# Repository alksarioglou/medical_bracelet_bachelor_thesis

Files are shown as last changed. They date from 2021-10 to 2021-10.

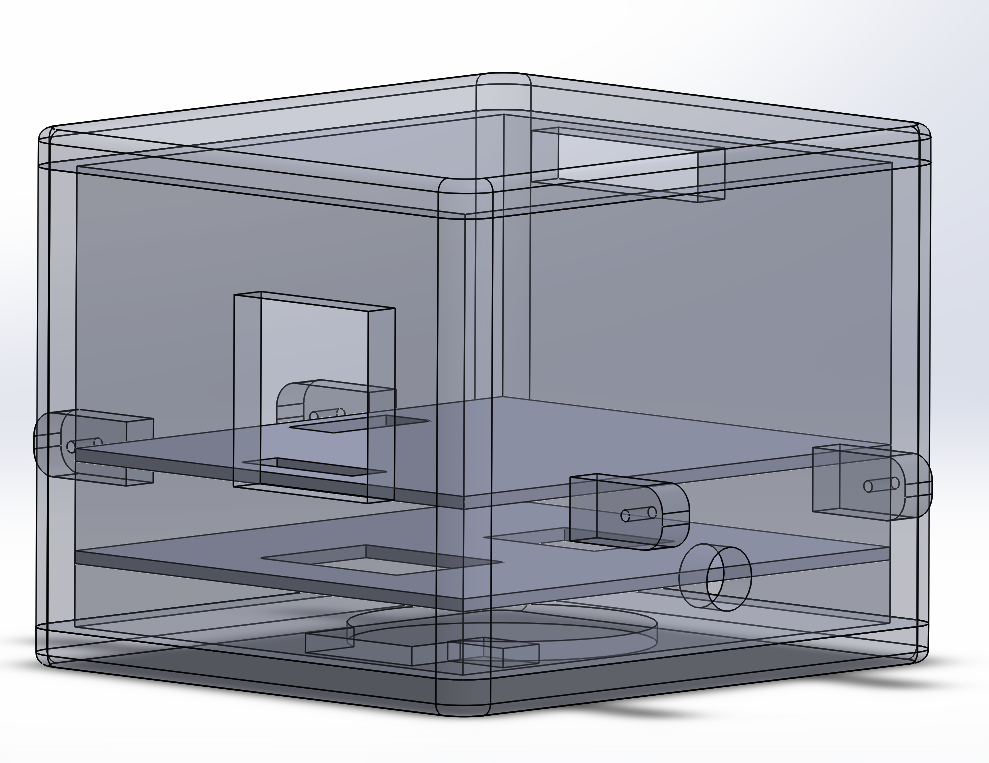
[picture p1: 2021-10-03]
CAD_Models/Non-transparent Intermediate Overview.png

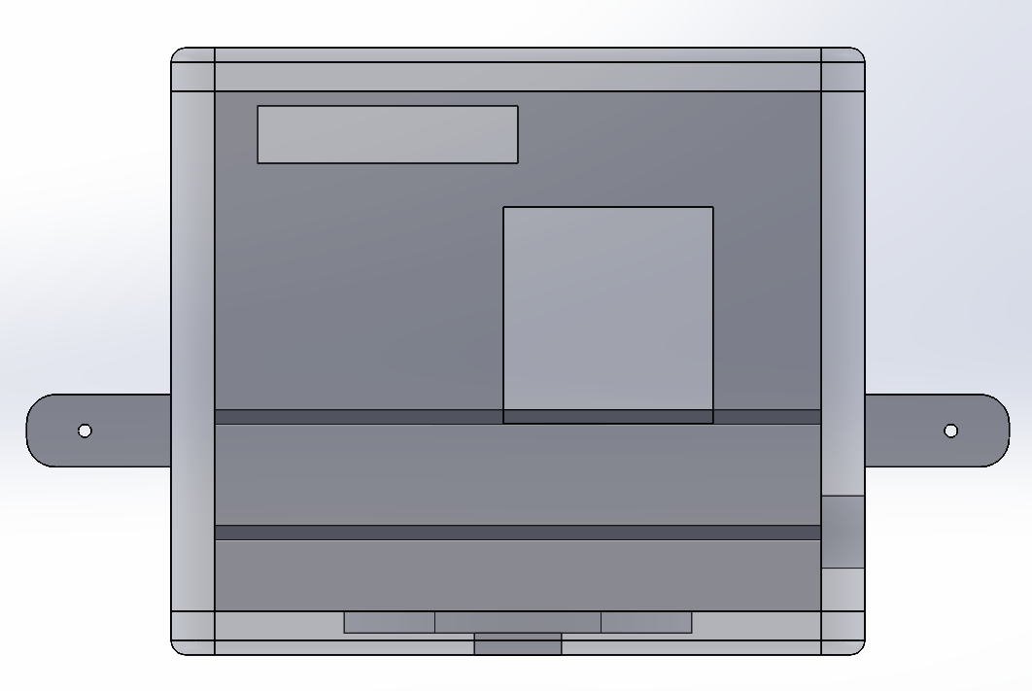
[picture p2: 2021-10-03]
CAD_Models/Non-transparent Intermediate Side View.png

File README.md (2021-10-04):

# Bachelor Thesis - Final Year Project - Medical Bracelet sends data (Heart-rate / ECG) to Webpage and Mobile App in real-time
- Development of a **portable medical bracelet** which combined both heart rate and electrocardiogram measurements transmitted wirelessly to a webpage and a mobile application in real-time 
- Achieved heart-rate measurements with **error of only 0.46% when compared to Apple Watch** 
- Sensor interface using **Arduino IDE**
- Webpage development using **Ubidots IoT Cloud Service**
- Mobile App development using **Blynk**
- Achieved **82% in the Bachelor Thesis (First-Class)**

## Organisation of Repository
- In `CAD_Models`, the 3D CAD designs of the bracelet are included which were implemented in **SolidWorks and 3D-printed**
- In `Component_Testing`, the source code used to test the heart-rate, ECG sensors and the Wi-Fi modules is presented (**Arduino and C++**)
- In `PCB`, the designs of the PCB integrating all components are found designed in **Altium PCB Designer**
- In `Reports`, all the **files that documented the progress of the project** throughout the year are presented

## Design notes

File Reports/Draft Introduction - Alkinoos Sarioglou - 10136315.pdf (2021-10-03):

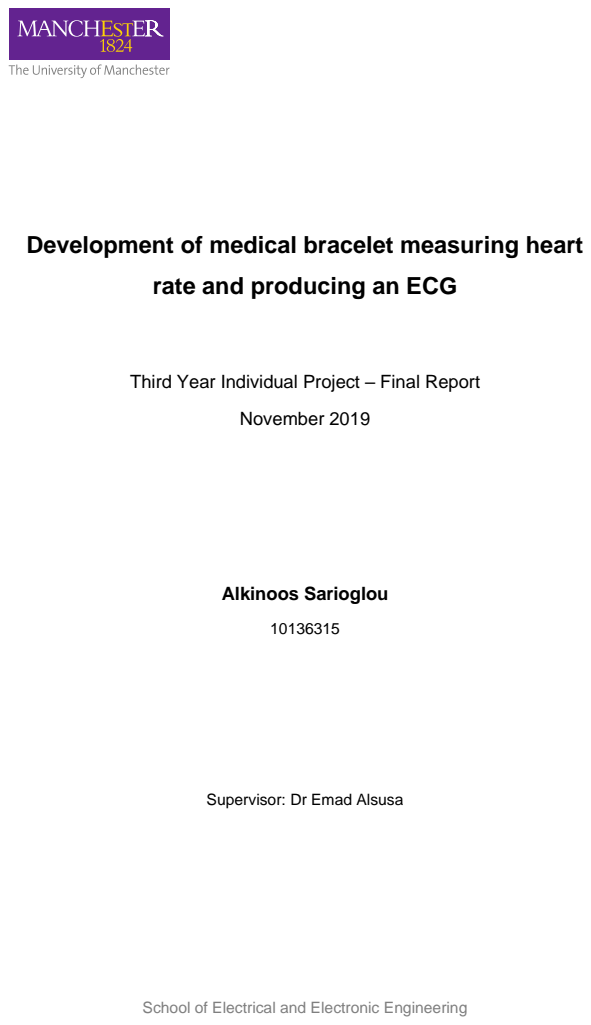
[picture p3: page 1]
November 2019; Alkinoos Sarioglou

Development of medical bracelet measuring heart

rate and producing an ECG

Third Year Individual Project – Final Report

Supervisor: Dr Emad Alsusa

School of Electrical and Electronic Engineering

School of Electrical and Electronic Engineering

Contents

School of Electrical and Electronic Engineering | Page 1

Introduction

Portable medical devices are becoming more popular these days due to the

revolutionization of this industry. Sensors that can measure the heart rate or produce

an electrocardiograph (ECG) have not only become more accurate but also smaller.

These are incorporated in wearable devices enabling people to track their own vital

measurements in real-time. As a result, regular meetings in the doctor are avoided

and heart abnormalities can be detected instantly leading to prompt treatment.

Undoubtedly, the advancement in medical devices should be accessible to all people

regardless of age, technological literacy or financial background. That is because the

data acquired by these devices are critical for everyone to stay healthy and diminish

the possibility of a fatal incident. However, the latest portable medical devices, in the

form of a bracelet mostly, discourage a wide range of people from using them due to

increased complexity and cost or due to limited functionality of communicating data

to a doctor in real time.

More specifically, some devices require connection to a nearby smart device, such

as a smartphone or a tablet. These gadgets are the only way to collect the recorded

data and display them for analysis and detection of potential flaws. This feature

already restricts many categories of people to have their vital data measured due to

limited abilities using technological equipment. There is a high possibility that the

ones affected the most are old people who most of the times do not possess one of

the smart devices. Ironically, they are the ones who need these devices the most, as

the measurements of heart rate and ECG need to be monitored constantly so that

dangerous situations can be dealt with immediately.

As it is understood taking real time and continuous measurements is the most

essential feature that these devices need to incorporate. Also, the communication of

these data to a specialist, such as a cardiologist, is critical so that the correct

interpretation of the results can be guaranteed and prevention of undesired incidents

is ensured. All of these characteristics are partially or not at all included in the

medical bracelets in the market, as they pose challenges in battery life and most of

all cost.

The increasing cost of development of such devices is reflected on the high selling

price. It is a fact that a lot of people are not able to afford prices that start from £80 and can reach the level of £500. Hence, it is understood that there are numerous

challenges to be overcome in the development of medical bracelets.

The aim of this project is to develop a low-cost medical bracelet which measures the

heart rate and the electrical activity of the heart continuously, in real time and can be

used without requiring a connected smart device. The communication of data will be

implemented through direct Wi-Fi to a cloud and the results will be displayed in a

webpage and an app. These two streams of displaying information will be used by

doctors to track the condition of their patients and detect abnormal activity. As a

result, they will be able to contact them directly and instruct them on which steps to

follow.

The main objectives of the project are directly related to the features that the medical

bracelet will incorporate. These include:

- Measurement of heart rate in BPM using a low-power heart rate sensor
- Measurement of the heart’s electrical activity using a low-power ECG sensor
- Communication of the above data to a cloud through direct Wi-Fi
- Display of the data on a webpage and an app in real time
- Development of app interface for doctors and patients

In order for the above to be achieved, a series of methods is followed. As a first step,

testing of different sensors for heart rate and ECG is performed in order to select the

ones which provide the best trade-off between cost, accuracy and size. Furthermore,

the available options in Wi-Fi modules are assessed in terms of cost, speed and

power consumption. A design of the overall circuit on a prototyping board follows

which integrates the mentioned components with the rest of the elements such as the

microcontroller and the battery. After that step is completed, the PCB is designed to

maximise the performance of the circuit and improve the communication of data

between the individual components.

The successful implementation of the PCB progresses the project to the software

development part. During this phase, the cloud is optimized to receive the data from

the Wi-Fi module. Following this, the webpage and the app are designed to collect

the information and display them in a user-friendly way. Finally, an early completion

of the above would allow for the 3D-printed design of the bracelet to be used with the system, otherwise an available one in the market will be used.

This report concludes the Final Year Project and summarizes the work undertaken

on planning, designing and implementing the low-cost medical bracelet. First, some

statistical figures related to fatal incidents from heart attacks or strokes prove the

need for this device. After that, the advantages and disadvantages of state-of-the-art

are thoroughly examined and the novel features of the proposed technology are

pointed out. Finally, the technical details of the project are presented and a

discussion of the results is included, assessing whether the project has been

successful in accomplishing the main aim.

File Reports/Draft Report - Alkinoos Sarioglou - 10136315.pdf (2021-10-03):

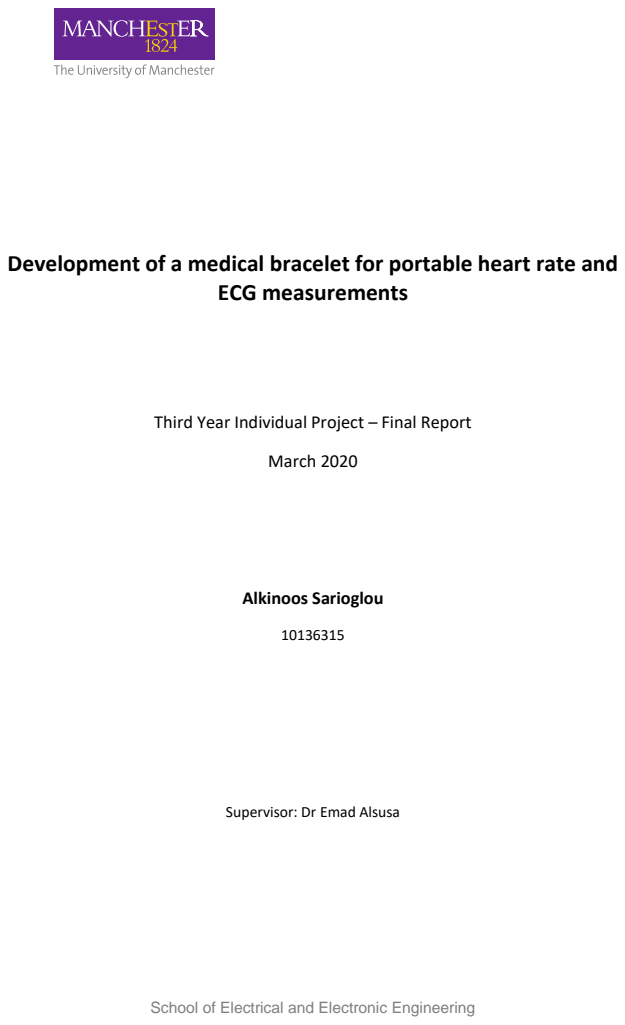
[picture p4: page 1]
ECG measurements; March 2020; Alkinoos Sarioglou

Development of a medical bracelet for portable heart rate and

Third Year Individual Project – Final Report

Supervisor: Dr Emad Alsusa

School of Electrical and Electronic Engineering

School of Electrical and Electronic Engineering

Contents

1.5.5. Recent research developments / Applications or implications of the research

13

School of Electrical and Electronic Engineering

School of Electrical and Electronic Engineering

2.8.3. Improving the Power Requirements and Cost | 58
2.8.4. Improving the Presentation of Results | 59
2.8.5. Improving the Security of Data | 59
Conclusions | 59
References | 60
Appendices | 64
Appendix 1 | 64
Appendix 2 | 67
Appendix 3 | 68
Appendix 4 | 72
Appendix 5 | 73
Presentation and Content (not included but marked) | 81
Formatting | 81
Spelling | 81
Grammar | 81
Figures | 81
Tables | 81
Diagrams | 81

Total word count: 17000

School of Electrical and Electronic Engineering | Page 1

Overview and Background

Abstract

It is a fact that heart attacks have always been responsible for a large number of deaths amongst

the population of the world. That is why since the beginning of medicine’s history, physicians have

been trying to find methods of identifying their symptoms in order to deal with them promptly

and save lives. One of the most efficient ways to detect these nowadays is heart monitoring. More

specifically, tracking of the electrical activity of the heart can demonstrate abnormalities of its

operation and immediate action can prevent fatal heart-related incidents. This would certainly

contribute to a patient’s longer lifetime.

There are two very important medical tools available today which enable doctors to check on the

vital information of their patients and acknowledge whether there are abnormalities or not. These

include the heart rate monitor and the electrocardiograph. The former one is using the technique

of photoplethysmography, in which an LED emits light on the skin and the amount of it reflected

to a photodiode is measured, demonstrating whether the change of blood’s volume is normal

during a heartbeat. The electrocardiograph is a device which uses electrodes attached to suitable

parts of the body in order to produce an electrocardiogram, a graph which monitors the electrical

activity of the heart by illustrating graphically whether its operation is regular. Therefore, it is

understood that these two tools should be easily accessible to all people in order to effectively

deal with heart-related accidents and as a result improve the life expectancy of the whole world

population.

In the last decade new technology has made these measurements available directly to the patients

with portable medical devices. Even though the existing state-of-the-art includes solutions which

extract vital information, the categories of people who can use them are limited due to the

following disadvantages:

- High cost
- Complex use of the technology
- Unable of communicating data to a doctor

The first problem constraints the use of these tools to people with limited financial background.

The second disadvantage does not allow older people with inadequate technological literacy to

have access to their medical information themselves. Finally, the feature of transmitting the live measurements to a doctor, in order for a meaningful analysis to be carried out, is missing from all

of the current state-of-the-art.

By considering these limitations, this project proposes the development of a low-cost medical

bracelet which can be easily worn by any patient on their wrist. The measurement of heart rate

and the electrocardiogram are produced in real time and are transmitted to a webpage or a

mobile application, where the doctors can view the information about their patients’ health and

take immediate action in case of an emergency.

In order for this to be achieved three components are necessary. First of all, a heart rate sensor is

required, which incorporates an LED and a photodiode, to extract the heart rate of the patient in

Beats Per Minute (BPM). Furthermore, an electrocardiograph sensor is used, which uses three

electrodes and measures the voltage difference between them, in order to produce the

electrocardiogram. In addition, a Wi-Fi module is added in order to communicate the data from

the sensors through an Internet-of-Things Cloud to a webpage and a mobile application. For all of

the above, different off-the-shelf components are tested and their accuracy is compared with the

Apple Watch Series 5 as a benchmark [1]. Then the most suitable ones are selected for the device

depending on the cost, size and accuracy. As a last step, a custom-made bracelet is designed, 3D-

printed and assembled with the circuit of the device to conclude the development of the proposed

solution.

The final part concerns a discussion which assesses whether the final product has accomplished its

aim in producing useful results for both patients and doctors. Also, the limitations of the

technology such as the accuracy of the sensors, the battery life and the charging time are analysed

and an evaluation on how they would restrict the device’s use by the customers is carried out.

Finally, the discussion investigates the further steps that would be followed should a marketing of

the product was decided, including Intellectual Property issues.

Future improvements: Reduce the parts about how I was planning to do it, e.g. too many details

about which components will be used and what the problems of the state-of-the-art is, put

more details on the results of the technical work after it is done, focus on the content of the

WHOLE report, put all additional background info in the Introduction. REDUCE SIZE

Introduction

Introduction of the project, get attention with the first sentence, give a hint of what you found out

through this project

Heart rate monitoring has been a priority of physicians and cardiologists since the beginning of the 20th century in the effort to deal with heart-related fatal incidents. The first big invention in this

field dates back to 1901, when Willem Einthoven created the first 3-lead electrocardiograph by

using a string galvanometer [2]. This development revolutionized the area of physiology and in the

following years many more improvements where made leading to the 12-lead electrocardiograph device as it is known now. Therefore, the end of the 20th century found physicians and doctors

more capable of detecting and dealing with cardiovascular problems rather than at its beginning.

However, some limitations were still apparent. The measurements of heart rate and the

electrocardiogram could only be taken in hospitals and medical practices, restricting patients’

flexibility on monitoring their health. As a result, at the start of the 21st century the focus of

medical devices industry shifted to giving control to the patients over their own medical data. That

is how the first personal health-monitoring technologies appeared.

Portable medical devices are becoming more popular these days due to the revolutionization of

this industry. Sensors that can measure the heart rate or produce an electrocardiogram (ECG)

have not only become more accurate but also smaller. These are incorporated in wearable devices

enabling people to track their own vital measurements in real time. As a result, regular meetings

to the doctor are avoided and heart abnormalities can be detected instantly leading to prompt

treatment.

Undoubtedly, the advancement in medical devices should be accessible to all people regardless of

age, technological literacy or financial background. That is because the data acquired by these

devices are critical for everyone to stay healthy and diminish the possibility of a fatal incident.

However, the latest portable medical devices, in the form of a bracelet mostly, discourage a wide

range of people from using them due to increased complexity and cost or due to limited

functionality of communicating data to a doctor in real time.

More specifically, some devices require connection to a nearby smart device, such as a

smartphone or a tablet. These gadgets are the only way to collect the recorded data and display

them for analysis and detection of potential flaws. This feature already restricts many categories

of people to have their vital data measured due to limited abilities using technological equipment.

There is a high possibility that the ones affected the most are old people who most of the times do

not possess one of the smart devices. Ironically, they are the ones who need these devices the most, as the measurements of heart rate and ECG need to be monitored constantly so that

dangerous situations can be dealt with immediately.

As it is understood taking real time and continuous measurements is the most essential feature

that these devices need to incorporate. Also, the communication of these data to a specialist, such

as a cardiologist, is critical so that the correct interpretation of the results can be guaranteed and

prevention of undesired incidents is ensured. All of these characteristics are partially or not at all

included in the medical bracelets in the market, as they pose challenges in battery life and most of

all cost.

The increasing cost of development of such devices is reflected on the high selling price. It is a fact

that a lot of people are not able to afford prices that start from £80 and can reach the level of

£500. Hence, it is understood that there are numerous challenges to be overcome in the

development of medical bracelets.

The aim of this project is to develop a low-cost medical bracelet which measures the heart rate

and the electrical activity of the heart continuously, in real time and can be used without requiring

a connected smart device. The communication of data will be implemented through direct Wi-Fi to

a cloud and the results will be displayed οn a webpage and a mobile application. These two

streams of displaying information will be used by doctors to track the condition of their patients

and detect abnormal activity. As a result, they will be able to contact them directly and instruct

them on which steps to follow.

The main objectives of the project are directly related to the features that the medical bracelet

will incorporate. These include:

- Measurement of heart rate in BPM using a low-power heart rate sensor
- Measurement of the heart’s electrical activity using a low-power ECG sensor
- Communication of the above data to a cloud through direct Wi-Fi
- Display of the data on a webpage and an app in real time
- Development of app interface for doctors and patients

In order for the above to be achieved, a series of methods is followed. As a first step, testing of

different sensors for heart rate and ECG is performed in order to select the ones which provide the best trade-off between cost, accuracy and size. Furthermore, the available options in Wi-Fi

modules are assessed in terms of cost, speed and power consumption. A design of the overall

circuit on a prototyping board follows which integrates the mentioned components with the rest

of the elements such as the microcontroller and the battery. After that step is completed, the PCB

is designed to maximise the performance of the circuit and improve the communication of data

between the individual components.

The successful implementation of the PCB progresses the project to the software development

part. During this phase, the cloud is optimized to receive the data from the Wi-Fi module.

Following this, the webpage and the app are designed to collect the information and display them

in a user-friendly way. Finally, an early completion of the above would allow for the 3D-printed

design of the bracelet to be used with the system, otherwise an available one in the market will be

used.

This report concludes the Final Year Project and summarizes the work undertaken on planning,

designing and implementing the low-cost medical bracelet. First, some statistical figures related to

fatal incidents from heart attacks or strokes prove the need for this device. After that, the

advantages and disadvantages of state-of-the-art are thoroughly examined and the novel features

of the proposed technology are pointed out. Finally, the technical details of the project are

presented and a discussion of the results is included, assessing whether the project has been

successful in accomplishing the main aim.

Feedback: excellent work overall. perhaps a bit more on state of the art / available products

with referencing would have been useful.

Motivation

According to official statistics from the World Health Organization, cardiovascular diseases have

been the biggest cause of death globally in the last 15 years and continue to account for the most

deaths annually even today [3]. More specifically, heart-related diseases were the reason why 17.9

million people died in 2016, which represented 31% of the death causes globally. In this category

of diseases, heart attacks and strokes are included and are the leading causes, being responsible

for the 85% of the overall heart-related deaths. It is worth looking into how these can be

diagnosed and the steps followed for their treatment.

### 1.3.1. Heart attack

First of all, a heart attack is a very serious medical condition in which the heart is not supplied with

the blood and oxygen required due to a blood clot blocking the blood’s flow in the coronary artery

[4]. As soon as there is a deficiency of blood to the heart muscle, the symptoms begin to appear.

These can include: chest pain, sweating, dizziness, shortness of breath and many more. According

to the NHS, “if a heart attack is suspected, the patient should be admitted to hospital

immediately” [5] in order for the effect of the heart attack to be minimal. The first test that is

being carried out to the patient is an electrocardiogram. This can determine how much the heart

has been affected and what type of heart attack the patient went through, in order to maximise

the efficiency of the treatment [6]. It is important to note that this test needs to be performed as

close to the time of the heart attack as possible in order to prevent further damage of the heart

and initiate the medical care actions promptly.

Doctors and health organizations advise that in heart-attack incidents a quick detection and

treatment is critical [7], in order to open the blocked artery and mitigate the effect to the patient.

It is worth noting that the best period of time to heal a heart attack is within the first 2 hours after

the occurrence [8]. Taking more time than that to detect it and react could result in more

detrimental effects to the cardiovascular system and fewer possibilities of survival. As a

conclusion, time is of the essence when it comes to a heart attack and it is vital to be able to

identify it immediately in order for the doctors to provide treatment without delay and avoid life-

threatening situations.

### 1.3.2. Stroke

Another fatal cardiovascular disease is called a stroke. This occurs when the supply of blood to the

brain is blocked, due to either a blood clot in arteries (ischaemic stroke) or burst of a blood vessel

providing oxygen and blood to the brain (haemorrhagic stroke) [9]. Its symptoms include inability

to move parts of the body such as face muscles or the arms and the legs [10]. Furthermore, speech

impediment might be observed as well as many more effects related to loss of balance, dizziness

or unconsciousness. In this case, it is also crucial that the stroke is identified immediately, so that

the patient can be transferred to the hospital. Then, the first actions to be taken are different

kinds of tests and scans to extract information on how much the brain was effected and which

treatment process should be followed. Apart from brain scans and blood tests, the heart rate is

thoroughly checked in order to detect irregular heartbeat and to provide information to the doctors about its causes. NHS points out that “a stroke is a medical emergency and the patient

should call 999 when it is suspected” [10], therefore no time should be wasted in the diagnosis of

a stroke as it could turn into a fatal incident.

Additionally, treatment methods are most effective when performed within the first 5 hours from

the occurrence. More specifically, medicine taken to remove the blood clot and sooth an

ischaemic stroke can have a much bigger effect if they are taken immediately after the incident

[11]. Other methods include a thrombectomy, during which a device is injected in the artery to

help in restoring the blood flow by dissolving the blood clot. In this case as well, NHS advises that

“it is most effective when started as soon as possible after a stroke” [11]. From the above, it can

be understood that time efficiency is also vital in a stroke in order to prevent a dangerous

situation for the patient.

### 1.3.3. Low and medium income countries

Another interesting figure is presented in the study of the World Health Organisation (WHO) on

Cardiovascular Diseases (CVDs), which states that “over three quarters of CVD deaths take place in

low- and middle-income countries” [12]. Therefore, the conclusion can be drawn that countries

which are not able to provide a quality healthcare system, due to financial instabilities, are the

ones whose citizens are more susceptible to suffer from heart-related diseases. At another point

of the WHO’s report, it is mentioned that “people in low- and middle-income countries often do

not have the benefit of integrated primary health care programmes for early detection and

treatment” [12]. In other words, there are no medical facilities or technological advancements

accessible which can aid in the detection and the healing of such diseases, posing many obstacles

in these countries’ citizens to stay healthy. As a result, many people, especially those with a

disadvantaged financial background, who are affected by CVDs die young because of late

detection and treatment.

In an effort to deal with these world issues, the World Health Organization has composed an

Action Plan for 2013-2020, which aims to reduce by 25% the risk of mortality from CVDs [13]. The

plan includes 6 objectives, which need to be completed in order for the main aim to be

accomplished. One of these relates to “raising the priority of the prevention and control of CVDs

by international cooperation” [13] giving some suggested actions to the private sector. In these

actions, an important point emphasizes the need to “promote (…) the creation of information and

electronic communication technologies (eHealth) and the use of mobile and wireless devices

(mHealth)” [13] in order to “empower people with noncommunicable diseases to seek early

detection and manage their own condition better” [13].

From all of the above, it can be recognized that it is of paramount importance to deal with the

leading cause of death globally, the cardiovascular diseases. By following and supporting the

Action Plan set by the World Health Organisation, the proposed device in this paper provides early

detection of the disease, enables prompt treatment of the patient, but also constitutes a low-cost

solution which can be utilized in low- and middle-income countries to decrease the number of

deaths due to these diseases on a global scale.

Finally, another aspect of the motivation behind the suggested technology relates to the ageing

population. Old people due to reduced mobility find it difficult to schedule regular appointments

with their cardiologist to track the condition of their heart. This technology would allow them to

have their vital signs continuously monitored and in real time by their doctors. As mentioned

before, in case of an abnormality in the blood flow early detection could save their lives.

Future improvements: FIND REFERENCES IN LIBRARY WHICH STATE THESE INFORMATION

ABOUT HEART ATTACKS AND STROKES NOT ONLINE SOURCES

Statements of Aims and Objectives

Core Aims – what needed to be achieved by the project, represents the “what”

The aim of the overall project is the successful development of a working low-cost medical

bracelet, which can be easily used by people of all ages. This will incorporate the features of heart

rate monitoring and electrocardiography. Also, the complete design of a practical webpage or

mobile application which will be able to receive data from the bracelet and display them in a user-

friendly way.

Objectives – individual steps to get to the aims, represents the “how”

To accomplish the successful completion of the practical work but also of the final report by the

end of the year, a clear schedule needs to be designed. This will include the timeline of the

objectives that need to be carried out in order to reach the main aims. For the final report these

include taking care of the presentation and the content structure, but primarily writing the:

- Overview and Background sections, which include the abstract, aims, objectives, state-of-the-art
- Technical Achievement sections, which includes design, implementation, testing, results

Then, for the practical work these are:

- Components Selection/Order
- Circuit and PCB Complete Design
- Working Prototype
- Bracelet Complete Design
- 3D-print of Bracelet
- Bracelet and PCB Integration
- App Development
- Sensor Data receiving through Wi-Fi and displaying
- App Interface for Patients and Doctors

Literature Review

Check with the checklist provided in the book

### 1.5.1. General Introduction to the topic

When considering the future of medicine, it can be clearly foreseen that it will include wearable

electronic devices. The field has already entered a new area in which there is a transition from

population level to personalized healthcare [14]. This has been made possible by numerous

innovative devices being developed, which include a variety of advanced biosensors, such as

accelerometers, magnetometers, altimeters, GPS but with the dominant being PPG and ECG

sensors. On one hand, ECGs are the most commonly used diagnostic tools in healthcare conveying

useful information on the cardiac electrical cycle. On the other hand, PPG sensors deliver

measurements on the heart rate of the patient, which is widely used as a helpful indicator on the

physiologic status of the patient’s heart. Therefore, the widespread use of these non-invasive and

cost-effective sensors in the new devices can be justified as it aims to provide users with an

individualized way of monitoring of their vital signs [14]. A study demonstrated that 71% of new

devices included a PPG sensor which outnumbers all the other available sensors, including GPS

[15]. However, these gadgets go beyond just extracting medical data. They incorporate wireless

and mobile communication to transmit the real-time data to a physician or even run algorithms to

predict events before they occur and prompt patients to take action, such as adjusting their

medication. As a result, an individualized, continuous and passive monitoring is achieved providing

great advantages for the users and doctors. These innovations have driven the market of wearable technology into a rapid growth phase and the healthcare informatics that will be generated bring

the sales potential to the range of billions of dollars [16]. That is why many industry leaders, such

as Apple and Fitbit, as well as start-ups invest a big share into research of user requirements in

order to reinforce the market with integrated devices that provide a wide range of measurements,

such as movement tracking and heart monitoring. After all, new studies bring to light the need of

patients to possess these devices, as one in six consumers in the United States already use

wearables including smartwatches or fitness bracelets [17]. Therefore, it is safe to say that the

healthcare industry has enter an era of revolutionization.

### 1.5.2. Importance of the topic

The value of the wearable devices, such as the medical bracelet developed in this project, lies on

the detection and prevention of life-threatening heart conditions. The integrated PPG and ECG

sensors can be vital in indicating signs of heart irregularities. More specifically, PPG sensors have

many uses such as in clinical physiological monitoring, to determine heart rate, blood oxygen

saturation and blood pressure, in vascular assessment to indicate arterial diseases as well as in

autonomic functions to measure blood pressure and heart rate variability and many others [18].

On the other hand, the functions of an ECG sensor are equally important, as it utilized to “analyse

cardiac rhythm, ischemic changes and to predict and treat acute myocardial infractions and

coronary events” [19]. Furthermore, it is a useful tool in the diagnosis of cardiovascular diseases

such as “cardiac dysrhythmia, congestive heart failures (CHF), coronary artery disease, heart

attack, bradycardia and tachycardia” [19]. However, one of the most serious heart problems is

atrial fibrillation, which can result in stroke or heart failure if it remains undiagnosed and

untreated promptly [20]. Both PPG and ECG sensors can significantly contribute to the early

detection of the disease and enable doctors to take quick action. Lately, devices using PPG have

become enforced with algorithms that analyse the measured data and are able to detect signs of

atrial fibrillation [21]. For instance, Apple Inc. has included that feature in the development of its

product, Apple Watch, and the Apple Heart Study performed by Stanford Medicine demonstrated

that 84% of the 400,000 participants who received irregular pulse notifications actually suffered

from atrial fibrillation giving a small indication that these devices can contribute in early detection

[22]. Another important advantage will be the opportunity to study ECGs more thoroughly in order

to correlate patterns in the waveforms and symptoms with heart diseases and particularly in

infrequent symptoms due to the continuous monitoring capability [23]. Additionally, these

measurements are also significant for sport activities and as a psychophysiological status indicator, such as in stress measurements [24].

### 1.5.3. Historical Origins

The interest of physicians to study the electrical activity of the heart dates back in the mid of 19th

century, when Dr. Carlo Matteucci, a physics professor in Italy, proved that there was electrical

current associated with every heartbeat of a frog [25]. This inspired more research into the field

and in 1856 physiologists managed to record a cardiac potential, which reassured them that there

was electrical activity in the human heartbeat as well [26]. Then, in the early 1870s two British

physiologists used a capillary electrometer to record the heart’s electrical current successfully [26]

before Augustus Waller, a British physiologist, published the first ever electrocardiogram from a

human heart using this device combined with the electrodes placed on the back and the chest

[27]. The last decade of the 19th century was a very active period for physicians who

experimented with technology to detect the electrical activity of the heart and attempt to extract

more useful information. The intense research became fruitful when in 1895 the Dutch

physiologist Dr. Willem Einthoven refined the original capillary electrometer and had

demonstrated the five deflections that occur during a heartbeat [26]. The deflections were given

the names of PQRST respectively because of a mathematical tradition that had been established

by Rent Descartes and which are still used in ECGs until today [26]. He then developed a highly

sensitive string galvanometer – an electromechanical instrument to detect electric current – to

detect the potential difference between the attached electrodes resulting from the different

stages of the heart pumping blood. Finally, in 1902 the first electrocardiograph was officially

introduced by Einthoven which incorporated a silver-coated string which moved from side to side

in the strong magnetic field of a magnet when the heart’s current passed through it [26]. The

oscillations of the string were magnified by a microscope and were recorded photographically to

illustrate the magnitude and direction of the current. This Nobel Prize-winning invention was vital

and initiated new fields of research to use the ECGs to diagnose irregular heartbeat but also to

connect patterns in the graph with heart conditions such as atrial fibrillation or ischemic heart

disease. In 1930, the ECG had developed that much that it could used on its own to confirm the

diagnosis of myocardial infarction with certainty [25]. Around that time, another improvement

came to life as Dr. Frank N. Wilson introduced the ‘central terminal’, the connection between the

three limb electrodes, which was considered as ‘ground’ [25]. Building on that, the American Heart

Association and the Cardiac Society of Great Britain recommended the exploration of heart activity

from six sites named V1 through to V6 across the precordium [26]. Another milestone includes the introduction the augmented unipolar limb leads called a-VL, a-VR and a-VF which provided more

thorough coverage of the area around the heart [25]. All these innovations contributed to the

introduction of the 12-lead electrocardiogram in 1954 by the American Heart Association [25].

Later in the 20th century inventors started to think about making this instrument portable and

more easily accessible to patients. A pioneer physicist named Norman Holter managed to

implement an ambulatory electrocardiography device which could record an ECG continuously for

a couple of days [28]. The Holter monitor is still used today for a limited-time continuous recording

of an ECG [28]. Another pioneer Seppo Säynäjäkangas in 1977 invented the first wireless heart

rate monitor as a training tool for the Finnish National Cross Country Ski Team [29]. This marked

the beginning of the wearable devices industry.

Photoplethysmography also has a rich history which started in the 1930s. More specifically, the

beginning of this technique was introduced by an American research group which managed to

monitor blood volume changes in the human fingers with the PPG method [18]. In 1937, Alrick

Hertzman and his colleagues at the St. Louis University published a paper explaining the use of a

reflection technique to measure the changes of blood volume in the fingers [18]. Later on, they

continued improving the technique by amplifying the signal and describing ways of avoiding

sources of error, such as insufficient contact with the skin [18].

As a conclusion, many researchers contributed with their work in order for these ideas to be

widespread now and to be producing life-saving results. Since the time of their invention, ECG and

PPG techniques have developed by leaps and bounds and it is interesting to investigate how they

are used today and the kind of results that they produce.

### 1.5.4. Main theoretical and experimental findings

Undoubtedly, there has been an impressive development in the portability and size of the devices which measure heart rate and produce ECG graphs since the first inventions during the 20th

century. These advancements have attracted users to purchase them and utilize their features.

However, there is normally questioning about how accurate the output data is and whether the

machine learning algorithms to detect irregularities are efficient. Multiple studies have been conducted to assess the accuracy of marketed wearable smartwatches and medical bracelets and

the results are satisfactory. First of all, a research study in 2016 examined the validity of different

wireless heart-rate monitors such as FitBit Charge HR, Microsoft Band and others and after using

measurements from 50 volunteers the mean absolute percentage error values ranged from 3.3%

to 6.2% with the Polar RS400 HR chest strap as the benchmark [30]. Furthermore, another study

investigated if smartwatches in the market could accurately measure heart rate in people with

different heart conditions, such as sinus rhythm, atrial flutter and atrial fibrillation. 100

participants were tested at rest with 30 minutes of continuous monitoring. The results

demonstrated that in the cases of sinus rhythm and atrial flutter the FitBit and the Apple Watch

agreed strongly with the ECG benchmark device with a low average bias of 1 heartbeat [31].

However, in the case of atrial fibrillation there was a higher deviation from the benchmark

measurements with biases of around -15 heartbeats for each device [31]. Overall, this study

showed that the smartwatches underestimated the heart rate in patients with atrial fibrillation,

which limits their use but demonstrated good performance in all the other cases [31]. Additionally,

other solutions on heart monitoring were tested for their sensitivity and specificity. More

specifically, the Cardiio Rhythm Mobile Application, which measures the heart rate using PPG

techniques, was examined to determine whether it could accurately detect atrial fibrillation. The

results demonstrated that its sensitivity and specificity were 93.1% and 90.9% respectively, hence

showing reliable performance [20]. Finally, the iTransmit study assessed the quality of

measurements taken from the AliveCor Kardia Mobile device when attempting to detect atrial

fibrillation after ablation and found that it had 100% sensitivity and 97% specificity when

compared to a traditional transtelephonic monitor [32]. All of these results demonstrate that the

devices in the market can be trusted for the measurements they produce and more value is added

by their portability and miniaturized size. Nevertheless, the undergoing research is ongoing by

attempting to improve the features that wearable devices provide. The recent advancements in

the field promise an exciting future for the industry.

### 1.5.5. Recent research developments / Applications or implications of the research

The trend in the research field of wearable electronics currently focusses on developing flexible

and stretchable sensing circuits which will improve the user’s comfort of measuring the heart rate

and producing the ECG of the patients. In order to achieve mechanical flexibility, the device need

to incorporate stretchable substrates, appropriate conducting electrodes, suitable sensing

materials in the millimeter range and most importantly flexible primary batteries.

The field of stretchable batteries has introduced many advancements recently such as connecting

microbatteries on stretchable substrate or fabricating batteries in the shape of a cable [33].

Furthermore, there has been research on other ways of powering flexible sensors and solutions

such as photovoltaics with supercapacitors or thermoelectric generators, converting the heat of

the user’s body to electrical energy, were suggested [33]. Although these new powering

techniques of wearable sensors have enabled more creative systems to rise, they have brought

new engineering challenges to the surface. These relate to the integration of the power sources

with the biosensors, as they need to be physically close to the location where the signal is

measured. Also, their location on the body needs to allow sufficient primary energy to be collected

depending on its source. Furthermore, the materials used for the power source and the sensors

need to be dermatologically proven, safe and nontoxic so that the integrity of the user’s health is

ensured [33].

An innovation worth mentioning relates to an epidermal electronic system which apart from ECG

measurements it can also extract temperature and strain data by attaching the device on the

patient’s skin. The system uses an elastic polymer backing layer on which multiple sensors are

mounted along with a power and processing unit and a wireless transmission module [34]. On a

similar direction, the research group led by Zhenan Bao at Stanford University demonstrated

miniaturized monitoring devices with sensors in the millimeter scale which can measure the heart

pulses from the wrist in real-time with the use of flexible polymer transistors [35]. There are

multiple advantages in exploiting these innovations in future wearable devices which relate to low

power consumption and measurements unaffected by body movement artefacts. Another design

that exploits flexible materials in sensing is an ECG patch monitor which produces a single-lead

ECG by including an ADC to convert analogue ECG signals to digital form as well as an

accelerometer to remove any artefacts in the measurements caused by the movement of the body

[35]. It should be noted that body activity such as movement of arms and legs poses a significant

constraint on the achievable accuracy of the measurements. More specifically, the signal quality is

influenced by the electrode-skin impedance and the stability of the biomedical pads on the

patient’s skin. In the devices using PPG technique this limitation in addition to the artefacts due to

ambient light can lead to erroneous measurement of the heart rate. For this reason, algorithms

are currently evolving to remove variations in the measurements using adaptive filters and 3D

accelerometers [36].

An additional area of interest in the field of physiological sensing includes the use of electronic tattoos which can contains conventional components such as LEDs, transistors and more in

microscale patterns of silicon or gallium arsenide. These systems are advanced enough to be

powered wirelessly or using batteries embedded in the devices and produce ECG measurements

[36].

Furthermore, promising research activities in the field of wearable devices aim to connect the

sensing systems with clothes. This innovation will include microsensors embedded into textiles

which will extract useful physiological data for the patient and there will be an option to

communicate these to a cloud for doctors to inspect [37]. The smart textiles used incorporate

textile electrodes to acquire the signals which require reliable design in order to ensure good

signal quality and immunity to body movement artefacts [37]. It is believed that this technology

will contribute in the comfort of the user and will be able to provide a wide range of vital data,

such as breathing rate, blood pressure or body temperature as the sensing system will cover a

bigger area of the body. These measurements will be particularly helpful for specific groups of

people such as athletes, disabled people and also workers in hazardous places such as firemen.

However, there are obvious difficulties in implementing this vision, as these pieces of clothes will

require complicated manufacturing techniques. Also, the type of measurements required for users

with specific diseases will vary hence altering the complexity of the sensing circuits. Additionally, it

has not yet been determined if these technologies are water durable during washing cycles and

these could cause mechanical and chemical degradation. Therefore, another aspect of biosensors

that should be considered is their ability to overcome stress. All of these obstacles constitute

reasons why some initial attempts for implementation have failed [37].

### 1.5.6. Outstanding research problems

A further research problem includes the lagging development in the data analytics needed to

manage the enormous amount of data generated by the biosensors [14]. It is already obvious that

these sensors can measure a very wide range of quantities that will require algorithms to extract

the important information and provide useful notifications on emergency conditions. If the

advancements in machine learning become compatible with the diversity of data measurements,

then doctors and physicians will be able to master the interpretation of their patient’s information

and systems will predict potentially life-threatening events before they occur. To achieve this

target, it is crucial to determine the patterns in vital signs occurring during and before a heart

condition and establish normative data ranges which give confidence in the prediction of an event.

These features can then be exploited to provide patients with automatic suggestions for therapy

[18].

Measuring personal health data and communicating them over the wireless network has

justifiably made people skeptical about the security of their privacy [14]. The medical community

will have to find answers in the challenges of confidentiality and data security as these significantly

reduce the public acceptance to the wearable devices. Personal health information is protected

under the Health Insurance Portability and Accountability Act of 1996 [14] and to abide to this Act

all medical data extracted need to be encrypted when moved across secure networks in order to

protect patients’ privacy rights. A potential breach of personal health data would certainly be

disastrous for the industry and there would be no way back to a secure means of monitoring and

communicating vital measurements which could save lives.

Consideration of existing solutions

The field of medical devices is a fast-growing industry which is currently valued at USD 472.69

Billion and is expected to reach USD 612.7 Billion by the year 2025 [47]. More specifically, the

cardiovascular devices are likely to represent 13% to 15% of this share. Seeing this business

opportunity many companies have started developing medical products to enter the market and

become leading players of this promising industry.

Devices that measure vital signs, such as heart rate and ECG, can be distinguished in two

categories depending on their purpose. On one hand, those that extract cardiovascular data

during everyday activities, such as walking, running, swimming etc. allowing the users to monitor

their health data by themselves. In other words, they give easy access to the measurements,

without however providing a way of communicating the data to a doctor for medical monitoring.

These will be referred to in this report as Fitness Trackers. On the other hand, the second group of

devices displays the measured data to the user and also communicates them to a doctor, who can

keep track of the patients’ health condition in real-time. These devices will be referred to as

Medical Devices.

In the industry of Fitness Trackers, the heart-monitor bracelet called Fitbit dominates. The newest

version named Fitbit Charge 3 Fitness Activity Tracker provides useful features for its users, such

as continuous heart-rate tracking during walking, running, cycling, swimming and others, while

also monitoring the calorie burn and quality of the sleeping cycle [48]. Its major advantages include battery life of up to 7 days, waterproof design and an app for displaying the data. Some of

the disadvantages include no detection of heart rate irregularities, no ECG measurement and high

price of £150 [48]. Furthermore, another available activity-tracker watch is the Letsfit Fitness

Tracker. This monitor device also focuses on heart rate measurements during activities and

provides similar advantages in battery life as well as in the price, which is £25. On the downside,

the measurements are sometimes inaccurate and it does not notify the user for abnormal heart

activity. Additionally, a fitness bracelet called J-style Smart Wristwatch provides features such as

24-hour heart rate and ECG monitoring with abnormal heart rate alert in a reasonable price of

£25. However, it does not involve any communication of the data to doctors in real-time.

When looking at the state-of-the-art available in Medical Devices there are multiple approaches

on measuring the heart rate and the ECG. First, new products such as the Zio Patch or the

VitalPatch employ a patch which is attached on the patient’s chest and produces a 1-lead ECG

while also measuring the heart rate. This technique offers significant benefits in size as it does not

include bulky cables and in comfort of use as the device operates passively and stores the data for

analysis by a doctor, removing the need for the user to possess technical skills. However, both

demonstrate critical disadvantages. The Zio Patch is not capable of transmitting data in real-time,

but rather it records and stores measurements on the device for two weeks of monitoring. Then

the user sends the patch back to the manufacturer, which produces a thorough report on the

electrical activity of the heart over that two-week period [49]. Therefore, there is considerable

delay from the time of the measurement until the results become available. This procedure as well

as the high price of £150 classify it as an unsuitable option for heart condition monitoring.

Furthermore, the VitalPatch, even though it enables real-time analysis of data, it can only produce

a 1-lead ECG, which does not provide the necessary accuracy to detect heart arrythmias.

Other solutions include ECG pads such as the KardiaMobile device. This technology incorporates a

thin, rectangular device with two conducting pads, on which the users place two fingers in order

to produce a 1-Lead ECG on the screen of a smartphone. It can be attached on the back of a phone

for easy recording of measurements. The manufacturer has developed a mobile application which

receives the data in real-time and communicates them to a doctor [50]. The second version of the

device, KardiaMobile 6L, demonstrates improved accuracy as it can generate a 6-Lead ECG with

the addition of another electrode at the back side of the device [51]. Even though it provides a

reliable and accurate solution for heart rate and ECG measurement, the measurements can only

be recorded when the user is prompted to and not passively and continuously. For this reason, it is not a suitable solution for emergency situations as some heart irregularities might not be detected

in the 30 seconds of a single measurement taken by this device. Also, the acquisition of data

requires technical knowledge making it less accessible to older people who might struggle to use it

or who might not even possess a smartphone.

A final approach includes the multi-purpose watches which amongst all the other features they

provide, such as calls, messages, etc., they include the heart rate and ECG measurement as well

[52]. An example of this is the Apple Watch, whose price is very high due to all the additional

functionality that it offers to the user. Therefore, it is not considered as an option if the heart rate

monitoring functionality is the only one needed but if all the other features are also useful to the

user. Nevertheless, because of its accurate measurements of heart rate and ECG [1] it will be used

in this report as a benchmark to compare performance of the different sensors available and the

developed device as a whole.

To summarize, although the available state-of-the-art provides helpful solutions to produce

meaningful heart rate and ECG data, it was realized that none of the devices combines all of the

following features:

- Low cost
- Alerts for heart irregularities
- Communication of data to doctors in real-time
- Sufficient accuracy of the ECG measurement in order to detect heart arrythmias
- Continuous heart condition monitoring
- No technical skills required

Conclusions

By recognising the flaws of existing state-of-the-art, as presented in the “Consideration of existing

solutions” section, and the crucial impact that a heart rate monitor could have in the decay of

mortality rates, due to heart attacks and strokes, this report presents the process of developing a

low-cost medical bracelet, which will be accessible to all ages, regardless of technical literacy, and

will enable instant communication of heart rate and ECG measurements to a doctor for

continuous heart-condition monitoring.

The successful implementation of such device could potentially save lives and contribute to the 3rd

Sustainable Development Goal set by the United Nations for 2030, which aims at securing good

health and well-being for everyone at all ages [53].

Technical Achievement

Theoretical Development

### 2.1.1. Parts of the Heart

The heart is the most important muscular organ in the human body. It is located behind and to the

left side of the breastbone [38]. Its main functions include receiving blood low in oxygen from the

other organs and provide them with oxygen-rich blood, which allows the normal operation of

many body functions [38]. This is achieved through a network of arteries and veins which connect

the heart to the rest of the body, which is called the cardiovascular system.

The heart consists of four chambers [24]:

- The right atrium, which receives low-oxygen blood from the veins and forwards it to the right ventricle through a valve
- The right ventricle, which receives the blood from the right atrium and forwards it to the lungs, where it is filled with oxygen
- The left atrium, which receives the oxygen-rich blood from the lungs and forwards it to the left ventricle and
- The left ventricle, which pumps the blood to the rest of the body organs
Therefore, there are two blood circulation “loops” the body, one of them through the lungs, called

pulmonary circulation and one through the body, called systemic circulation.

What is remarkable about the operation of the heart is that it is self-exciting, which makes it a

unique muscle in the body as it does not require a nervous stimulus for excitation as all the others.

Figure x demonstrates the chambers of the heart diagrammatically.

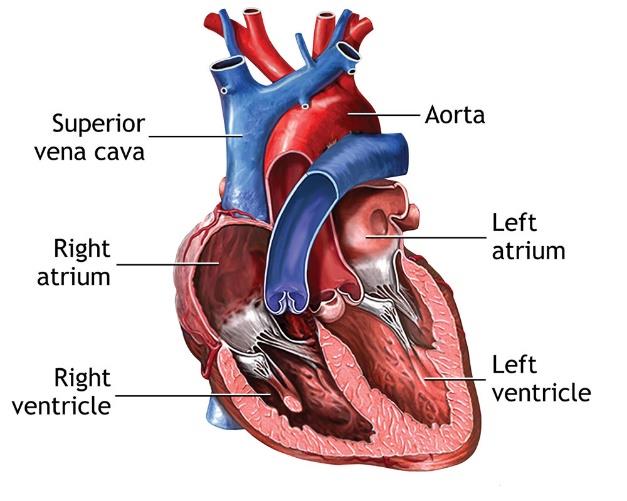
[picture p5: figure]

[39]

### 2.1.2. Cardiac Cycle

The cardiac cycle refers to a complete cycle of operation of the heart’s atria and ventricles, in

which the oxygen-low blood is received, pumped into the lungs, oxygenated blood is received by

the heart and then it is forwarded to the rest of the body [40]. It is characterised by contraction of

the heart muscle for a fraction of the cycle, called systole and relaxation called diastole [40]. These

changes in the shape of the heart are reflected in the depolarization and the repolarization of the

chambers [40]. Depolarization refers to the change of the electric charge distribution in the cells of

the chamber resulting in less negative charge inside them. On the other hand, repolarization is

related to the change in the charge distribution back to a negative value after depolarization. An

efficient coordination between the atria and the ventricles in order to ensure normal operation of

the circulation mechanism.

A full cardiac cycle consists of four phases [40]:

- Atrial systole, during which there is contraction of the atria and the blood received by the veins is pumped into the ventricles. This results from depolarization of the atria and lasts around 100 ms
- Atrial diastole, during which there is relaxation of the atria after pumping the blood into the ventricles
- Ventricular systole, during which there is relaxation of the atria and contraction of the ventricles. The blood flows from the right ventricle to the lungs and from the left ventricle to the rest of the body. This is a result of depolarization of the ventricles and lasts around 270 ms
- Ventricular diastole, during which there is relaxation of the ventricles. The blood flows back to the heart into the atria and eventually into the ventricles. It follows the repolarization of the ventricles and lasts approximately 430 ms.
Each deflection on the ECG represents a phase of the cardiac cycle [40]. More specifically:
- The P wave represents the depolarization of the atria during the Atrial systole phase
- The QRS complex represents the depolarization of the ventricles during the Ventricular systole phase
- The T wave represents the repolarization of the ventricles and indicates that the phase of ventricular relaxation begins
Figures y and z demonstrate the phases of the complete cardiac cycle as well as their connection

with the deflections appearing in an ECG

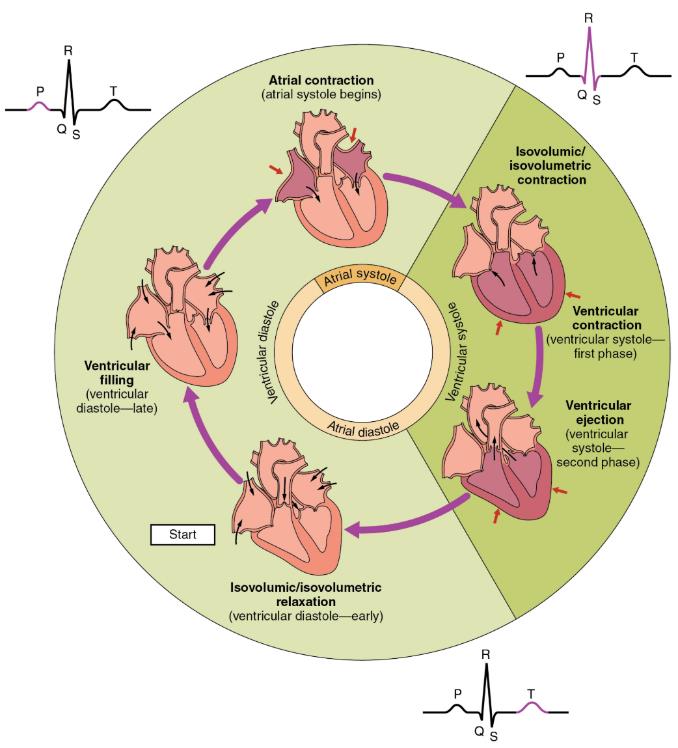
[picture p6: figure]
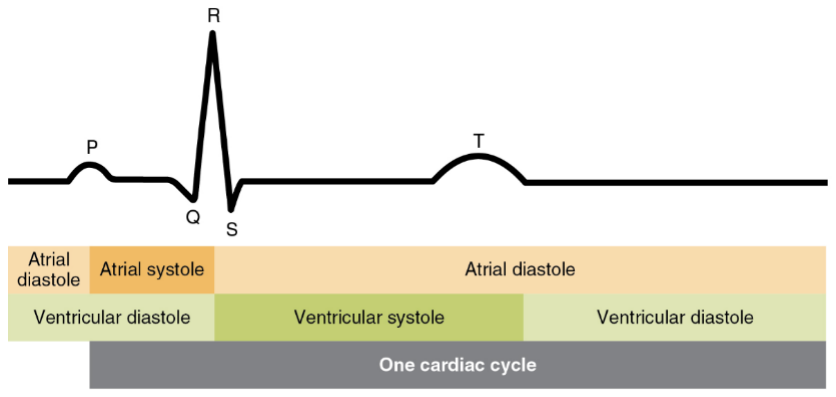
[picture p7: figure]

[40]

### 2.1.3. Heart Rate

The cardiac cycle is a periodic operation of the human body and therefore it is characterized by a

frequency. This frequency is varying according to nervous, hormonal and psychological influences

and it has been given the name of Heart Rate. Heart Rate is a crucial vital sign and has become the

most fundamental measurement in healthcare and fitness activities, as it provides useful

information on the physiologic condition of the heart. Its unit is Beats per Minute (BPM) [24]. It is

normally measured with a technique called Photoplethysmography (PPG). The quality of the

cardiac cycle can also be evaluated by the graphs generated in Electrocardiography (ECG), as these

illustrate the deflections corresponding to the depolarizations and repolarizations of the ventricles

and atria.

### 2.1.4. Photoplethysmography (PPG)

Photoplethysmography is an optical technique to detect the changes in the volume of the

peripheral blood flow throughout the cardiac cycle. This is achieved by integrating a system which

is composed of a Light-Emitting Diode (LED) and a photodiode, which is a sensor sensitive to

changes in light density [18]. The system can be attached to the wrist, fingertip, ear lobe or any

other capillary tissue. The operation principle is very simple and begins with the LED emitting light

(normally green) in a wavelength compatible with the photodiode on the skin tissue. The amount

of light reflected back to the sensor is measured by the photodiode and its variations are

associated with changes in blood volume and blood vessel wall movement at a particular instant

[18]. Figure k demonstrates the operation of a PPG sensor diagrammatically. The PPG waveform

produced can be divided into an AC component, which has a fundamental frequency proportional

to the heart rate and a DC component that relates to the average blood volume. In order to

achieve the best possible accuracy of measurements and reduce the size of the DC component,

the photodetector is normally connected to low noise circuitry including an amplifier and a high

pass filter, which also enables removing high frequency noise especially from mains power supply

interference [18]. The final stage includes intelligent algorithms to convert the measurements of

light intensity to the measure of Heart Rate in BPM. PPG sensors use dry sensors and are often

preferred by users as they are more comfortable to wear than ECG sensors, but also because they

can extract data for a wide range of quantities, such as oxygen saturation and blood pressure. This

is the reason why they are employed in multiple commercially available wearable products and

their popularity constantly grows.

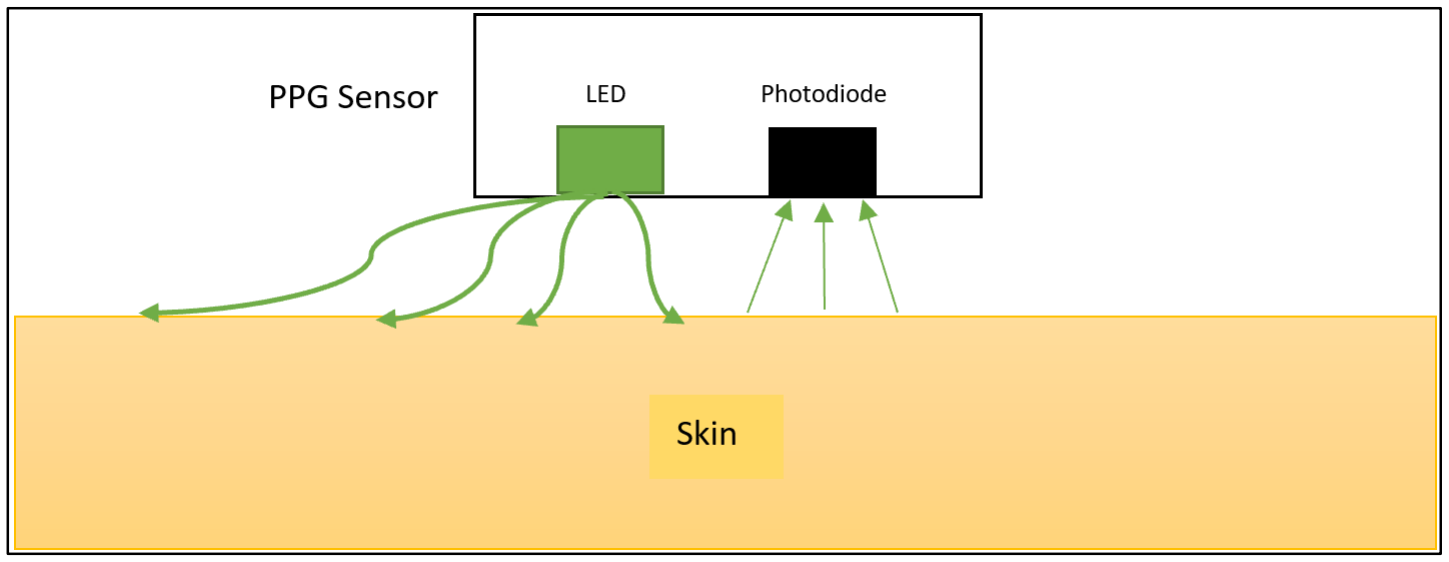
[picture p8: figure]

### 2.1.5. Electrocardiography (ECG)

Electrocardiography is a field of medicine which is related to the generation of electrocardiograms

(ECGs). These are graphs illustrating the electric potential of the heart over time and are produced

by clinical instruments called electrocardiographs. The output graphs are widely used by doctors

and clinicians as diagnostic tools to provide information on the cardiac electrical cycle [24].

Additionally, it is possible to make a thorough analysis on the cardiac rhythm, ischemic changes in

order to detect potential heart conditions, such as atrial fibrillation, cardiac dysrhythmia,

tachycardia and more [24].

Essentially, ECGs demonstrate graphically the heart’s atria and ventricles depolarizations and

repolarizations as explained in the previous section. These variations in the heart’s electric

potential is propagated in pulsating electrical waves through the skin. These are represented in

the graph as five deflections, named P, Q, R, S, T, U, which were given their names from the

inventor of the electrocardiograph Willem Einthoven, according to a mathematical convention

originated from the French mathematician, René Descartes [24].

Figure 32 shows a conventional ECG for a normal sinus rhythm, demonstrating that the electrical

activity of the heart is operating normally.

In order to extract this data, conductive electrodes need to be attached to the patient’s body in

appropriate positions.

### 2.1.6. Electrodes for Electrocardiography

The electrodes more commonly used in electrocardiography nowadays are made of silver/silver

chloride and they also include an electrolyte gel, which contains free chloride ions and is applied in

the contact point between the electrode and the skin [22]. Their principle of operation is based on

the transduction of ionic current at the surface of human tissues to electron current which is

delivered to the measuring instrument through a wire [24]. Furthermore, as the electrolyte gel is

the only part in direct contact with the skin it implements the crucial functionality of passing the

ion current from the skin tissue to the electrode which converts it to electron current. The

electron current can then be sensed by the electrocardiograph. This type of electrodes are

preferred over other available ones as they are characterized by low electrode-skin impedance,

low motion artefacts and reduced noise. Additionally, they are reliable and inexpensive. However,

there are drawbacks associated with their use such as skin irritation due to its adhesive properties.

Moreover, the gel can dry after long period of use making it unsuitable for long-term monitoring

applications. For this reason, research is currently active in the development of new types of dry electrodes which will minimize the problem of skin irritation but also provide reliability against

body movement artefacts [24]. Apart from the quality of the electrodes, equal significance is

posed on the body positions that the electrodes are placed on.

### 2.1.7. Placement of ECG Electrodes

The number of electrodes used for an ECG measurement can vary. It should be noted that the

higher the number of electrodes the better the accuracy in the output ECG graph. There are

different types of ECG which depend on the number of ECG leads that they produce. The term

“ECG Lead” means a graphical representation of an electric potential measurement between two

electrodes or a single electrode and the virtual electrode and it should not be confused with the

term “ECG electrode” which is the physical sensor to measure the potential at a specific position

on the body. Typical electrocardiograph instruments produce 1-lead, 3-lead, 6-lead or 12-lead

ECGs, which is the maximum possible. In this report the design of a 3-lead ECG is proposed

therefore the placement of the three electrodes for this type are discussed.

First of all, it is important to note that the placement of the electrodes needs to give a view of the

heart from different angles in the vertical plane parallel to the body. In the 3-lead ECG, each of the

three electrodes displays a different angle of the heart contributing in a multi-angle view of the

heart’s structure. The appropriate placement of the 3 electrodes corresponds to a triangle in order

to give equally-spaced views of the heart every 120° and it was introduced by Willem Einthoven in

the so-called Einthoven’s triangle [41]. In order for the electrodes to form a triangle, these are

placed in the following positions [41]:

- Right Arm (RA)
- Left Arm (LA)
- Left Leg (LL)
Using these electrodes different electric potentials are measured and drawn on the ECG graphs. In

a 3-lead ECG, there are three electric potential measurements that are performed and these are

the following:

- Lead I, which corresponds to the electric potential between the LA and the RA
- Lead II, which corresponds to the electric potential between the LL and the RA
- Lead III, which corresponds to the electric potential between the LL and the LA Einthoven’s Triangle is demonstrated in Figure n

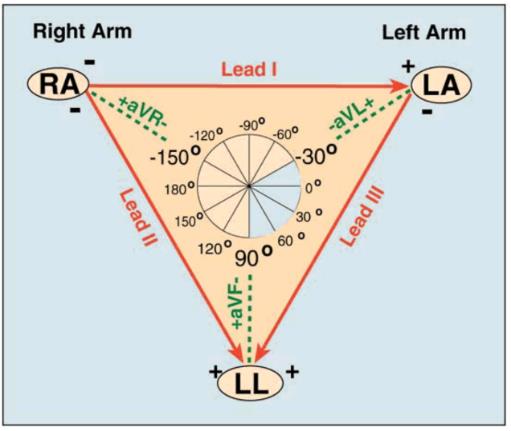
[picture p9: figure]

[42]

### 2.1.8. Measures of Accuracy

In engineering and science disciplines, it is important to be able to evaluate the accuracy in the

performance of a system when compared to a reliable benchmark instrument. Two helpful

measures which assess the accuracy of a device in evaluating whether a condition is present or not

are the sensitivity and the specificity. On one hand, the sensitivity measures the proportion of

positive cases that were actually identified by the device as positive [32]. On the other hand, the

specificity measures the proportion of negatives cases that were correctly recognized by the

device as negative [32]. Therefore, higher values of sensitivity and specificity demonstrate greater

accuracy of the system. In this report these measures will be used to evaluate whether the

medical devices can identify cases of heart conditions such as atrial fibrillation, atrial flutter as well

as normal sinus rhythm when compared to 12-lead ECG instruments or ECG chest straps.

Furthermore, the accuracy and precision of the Heart-rate measurements acquired by the PPG

sensors when compared to the benchmark device is evaluated by the following accuracy

measures:

- Mean value: The mean value of all the individual Heart-rate values extracted by the sensor used in this project are compared to the mean value of the measurements by the benchmark device. The least difference there is between the two, the more accurate the sensor is. [43]
- Standard Deviation (SD): The standard deviation measures the amount of variation of a set of measurements from their mean value. For xi being each individual measurement value and μ being the mean value for a set of N measurements, the standard deviation σ of the set is calculated using the following formula:

σ = √
∑(xi − μ)

2
Ν

The smaller the σ for the set of Heart-rate measurements the more precise the sensor is. It

is preferable that the standard deviation is small for both the PPG sensor used in this

project and the benchmark device. [44]

- Pearson Correlation Coefficient: The Pearson Correlation Coefficient measures the linear correlation between two variables X and Y. It has the value of +1 when there is total positive linear correlation, 0 when there is no linear correlation and -1 when there is total negative linear correlation. For cov(X, Y) being the covariance of X and Y and σX, σY the standard deviations of X and Y respectively, the Pearson correlation coefficient ρX,Y is calculated using the following formula:

ρX,Y =

cov(X, Y)
σXσY

It is desirable that the Heart-rate measurements from the PPG sensor will have as high

correlation coefficient as possible when measuring its linear correlation with the

benchmark device. [45]

- Mean Absolute Percentage Error (MAPE): The MAPE measures the mean value of the error between the measurements of the Heart-rate PPG sensor and the benchmark device. For A being the value from the PPG sensor and B the value from the benchmark device for a set of N measurements, the MAPE is calculated by the following formula:
MAPE = (
1
N

∑

A − B
B

N

t=1

) × 100%

The smaller the value of MAPE, the more accurate the PPG sensor is. [46]

Now that the theoretical knowledge required has been introduced, the point of attention is

transferred to the procedure followed in order to implement the medical bracelet successfully.

Methods

The successful implementation of the project, aiming to develop a medical bracelet for passive

monitoring of the heart rate and the ECG, required a clearly defined plan. Figure y shows the

Flowchart of the methodology:

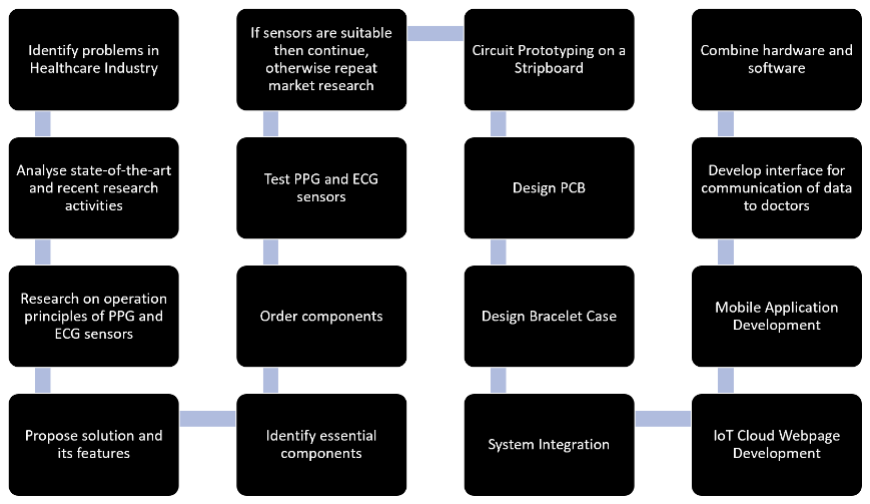
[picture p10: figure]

More specifically, the order of steps was the following:

- Researched on problems to be solved in healthcare industry and detected a need for a device which measures vital signs accurately, communicates them to a doctor in real-time and offers continuous monitoring without requiring technical skills, which would be particularly useful for elderly people
- Analysed the state-of-the-art solutions and recent research activities on the measurement of vital signs with portable medical devices
- Researched on the operation principles of the heart rate and ECG sensors and completed a Literature Review on the outstanding research problems
- Proposed a wireless medical bracelet which offers advantages such as simplicity of use, cost, continuous and passive monitoring, accuracy, communication of real-time data to a doctor enabling prompt action in emergency situations
- Identified what components were needed such as a Heart rate sensor, an ECG sensor, a Wi-Fi module, a Rechargeable Battery, a Battery Charger and platforms such as an IoT Cloud Service and a Mobile Application Development Platform
- Ordered off-the-shelf components which provided merits in size and cost
- Tested the correct functionality and accuracy of the sensors to decide on the most suitable ones for this application
- If at least one component of each sensor was suitable then proceeded with the next steps, otherwise repeated the market research on components or would produce custom-made sensors
- Prototyped a stripboard with all the system components and the interface circuit between them
- Designed the interface circuit between the components on a PCB
- Designed the bracelet case’s mechanical design on a 3D CAD tool (Altium, …), which was implemented by 3D-printing it
- Integrated the PCB with the components of the system
- Assembled the bracelet case with the PCB and the other electrical components
- Developed an IoT cloud page on the Ubidots platform where the information from the sensors is sent for displaying purposes
- Implemented the feature of sending automatic warnings through SMS in case of irregular heart condition

- Constructed a mobile application using the Blynk platform, which displays the heart rate and ECG on the screen of a phone
- Improved the feature of communicating the measurements to a doctor in real-time and enabled the direct communication between patients and doctors
- Combined the hardware design with the code to complete the product and project implementation

Feedback: a flow chart to provide a high level view of the methodology followed would be

helpful, In its current form the methodology appears to start immediately on the technical

choice of content without any introduction with an overall picture. Overall this a good piece of

work even though it lacks the precursor to the individual sections and the order and linkage

between them.

Design

### 2.3.1. Overview of Components

For the implementation of the medical bracelet the following electrical components were used:

- Heart-Rate Sensor
- ECG Sensor
- Wi-Fi module
- Rechargeable Battery
- Battery Charger
- Switch

### 2.3.2. Schematic Diagram

The following schematic diagram shows how the electrical components of the system were

connected:

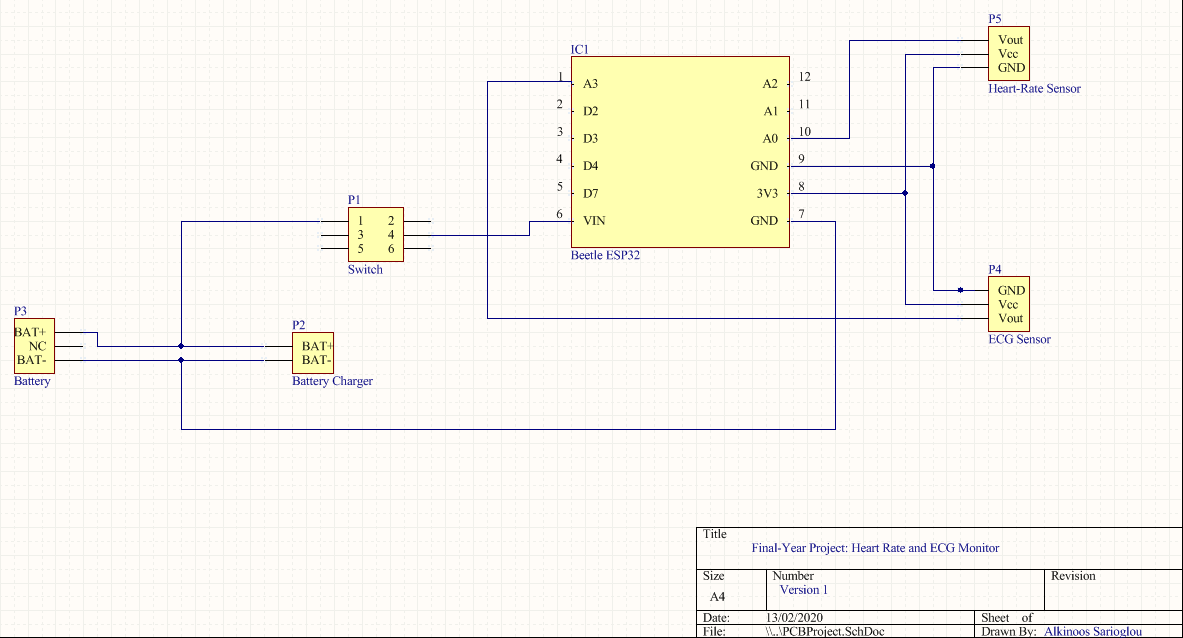
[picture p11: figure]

The schematic diagram is designed using a PCB design automation package (Altium Designer,

Version 20, Altium, California, USA).

### 2.3.3. Electrical Connections

As shown in Figure r, the following electrical connections were required between the components:

Wi-Fi module | Heart Rate Sensor
3.3 V | Vcc
GND | GND
Analogue Pin A0 | Vout
Wi-Fi module | ECG Sensor
3.3 V | Vcc
GND | GND
Analogue Pin A3 | Vout
Wi-Fi module | Battery
VIN | BAT+

GND | BAT-
Battery Charger | Battery
BAT+ | BAT+
BAT- | BAT-

### 2.3.4. Printed Circuit Board Layout Diagram

The interface circuit was then implemented on a single-layer PCB, which significantly reduced its

size making it easier to include in a medical bracelet device and less disturbing for the users. The

PCB Layout diagram as designed on the PCB design automation package (Altium Designer, Version

20, Altium, California, USA) is demonstrated below:

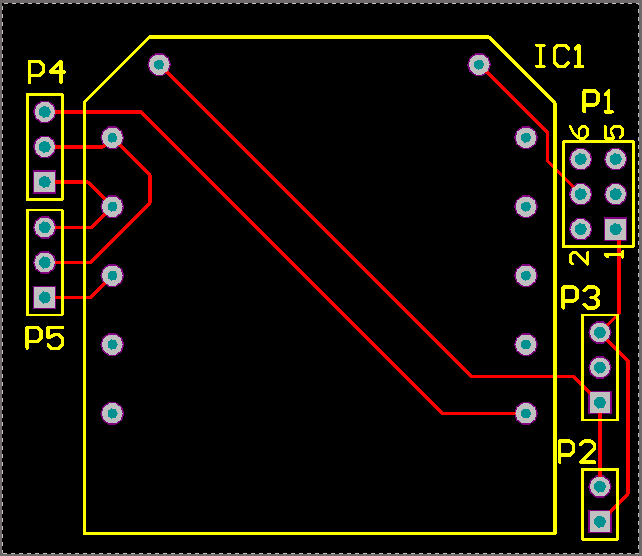
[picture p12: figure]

The designators shown on the PCB Layout Diagram of Figure 2 correspond to the following

components:

Designator | Component
IC1 | Wi-Fi module
P1 | Switch
P2 | Battery Charger

P3 | Battery
P4 | ECG Sensor
P5 | Heart-Rate Sensor
2.3.5. 3D-CAD Bracelet Case Design

The final part of the Design phase relates to the mechanical design of the bracelet case, which

included the electronics. The bracelet was designed on a 3D CAD tool (SolidWorks, Version,

Company, City, Country).

The size of the bracelet was limited by the size of the PCB and the area needed to fit all the

components of the system. Therefore, the dimensions of the bracelet were decided to be:

Width | 48 mm
Length | 53.5 mm
Thickness | 40 mm

The mechanical design of the system is composed of the following parts:

- Outer hollow Case (3D-printed)
- Cover Layer (3D-printed)
- 2 intermediate layers (Laser-cut)

The 2 intermediate layers separate the mechanical configuration of the components inside the

case into 3 levels:

- Top Level, which includes the PCB, the Battery and the Battery Charger
- Intermediate Level, which includes the ECG sensor
- Bottom Level, which includes the Heart Rate sensor

The configuration of the levels with the intermediate layers separating them is shown in Figure k:

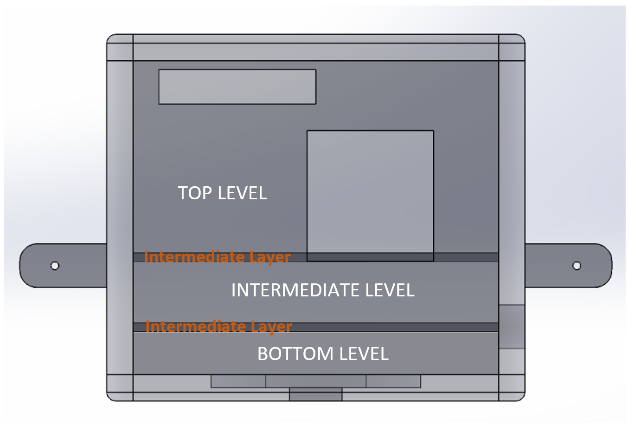
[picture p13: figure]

On the Outer Case, holes are included to allow for placement of the switch, the jack input port for

the ECG electrodes and the mini USB B port for charging the battery.

Overall, the high-level view of the bracelet case is the following:

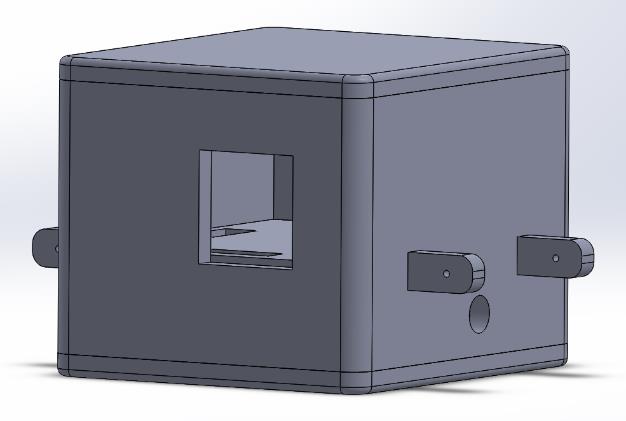
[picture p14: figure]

Then, the electrical components are inserted in the bracelet case and a watch strap is attached to

produce the final product:

Implementation

### 2.4.1. Electrical Components

How is the circuit designed, circuit diagrams, PCB diagram, 3D-CAD design of the bracelet

For the implementation of the medical bracelet the following six electrical components were

selected:

- DFRobot Gravity Heart Rate Monitor Sensor for Arduino
- Gravity Analog ECG Sensor for Arduino
- Beetle ESP32 Wi-Fi module
- Lithium Ion Polymer Rechargeable Battery
- Li-Ion Battery Charger Module
- Double-Pole Double-Throw Switch

Heart Rate Sensor

The Heart Rate Sensor uses the technique of Photoplethysmography (PPG) to record the heart

activity. Its operation is based on two green LEDs which emit light on the skin of the patient and

on a photodiode in the sensor which measures the reflected light from the skin tissues. The

photocurrent produced is then converted to an output voltage through a loading resistor.

Appropriate calculations in the code allow conversion of the output voltage to the value of heart

rate of the patient in BPM.

Two Heart Rate Sensors were tested, as described in the Testing section, in order to decide on the

most suitable one and in the end the DFRobot Gravity Heart Rate Monitor Sensor for Arduino was

selected for this application.

The integrated circuit (IC) of the sensor incorporates the SON1303 Integrated Heart Rate Sensor,

which includes the LEDs and the photodiode. Additionally, the SON3130 chip is included which

performs amplification of the photodiode’s voltage and provides the following advantages:

- Low input bias current of 10 pA
- Low supply current of 60 μΑ

This sensor satisfies the requirement of small size as its dimensions are 24 mm x 28 mm, which

means it can fit on an average person’s wrist and is compatible with the size of a bracelet.

Furthermore, it demonstrated more accurate measurements than the MAXREFDES117# sensor,

which lay closer to the data extracted from the benchmark device as shown in the Results section.

Finally, the cost was only 30p more expensive than the competitive sensor, therefore offering

more advantages for a negligible difference in price.

Some of its electrical characteristics include [54]:

Input Voltage | 3.3 V – 6 V (5 V recommended)

Output Voltage | 0 V – Vin (Analogue Mode) , 0 V / Vin (Digital Mode)
Operating Current | <10 mA

ECG Sensor

As seen in the Theoretical Development section, the operation of the ECG sensor is based on the

monitoring of the electric potential from the different electrodes attached in separate parts of the

body which are then combined to give the output ECG graph.

Even though there were very limited choices for ECG sensors in the market, the Gravity Analog

ECG Sensor for Arduino can perform a satisfactory ECG test on a patient which lies close to the

output graph from the benchmark device as seen in the Results section.

This sensor incorporates the AD8232 Heart Rate Monitor Chip by Analog Devices, which offers

great benefits [55] such as:

- Low supply current of 170 μΑ
- Common-mode rejection ratio of 80 dB
- High signal gain (G=100)

Additionally, it combines the voltage input of three electrodes attached to the appropriate

positions on the body, as described in the Theoretical Development section, to extract a 3-lead

ECG graph.

As the size is an important factor of the device as well, this IC’s dimensions are 35 mm x 22 mm,

which fits inside the dimension range of the bracelet.

Finally, its electrical characteristics include [56]:

Input Voltage | 3.3 V – 6 V (5 V recommended)
Output Voltage | 0 V – 3.3 V
Operating Current | <10 mA

Table 1: Electrical Characteristics of the DFRobot Gravity Heart Rate Monitor

Table 2: Electrical Characteristics of the Gravity Analog ECG

Wi-Fi Module

A Wi-Fi module is used for the communication of the Heart Rate data and the ECG output voltage

to an IoT Cloud Service, where the data is displayed in a user-friendly environment.

For this application, the Beetle ESP32 Wi-Fi module was selected as it provides Wi-Fi and

Bluetooth connectivity, multiple ADC channels for sampling the analogue voltages of the sensors

and GPIO pins.

This IC offers the following features:

SPI Flash | 16 Mbits
SRAM | 520KB
Crystal Oscillator Frequency | 40 MHz

The module provides a micro-USB port, in order to be able to program the board directly.

Furthermore, the board is compatible with the chosen programming environment (Arduino IDE,

Version 1.8.11, Arduino, Italy) and software support and libraries are provided.

The Wi-Fi module supports TCP/IP and a full 802.11 b/g/n Wi-Fi MAC protocol providing speed of

up to 150 Mbps, transmitting power of up to 20.5 dBm and the frequency range is between 2.4

GHz and 2.5 GHz [57].

The board provides advantages in size as well, as its dimensions are 35 mm x 34 mm.

Battery

It is critical to calculate the power budget required by the electrical components of the system in

order to select a suitable power source for the design. The power consumption of the individual

components is presented in Table n:

Component | Supply Voltage
| V (V)

Operating

Current I (mA)

Power Consumption

P=VI (mW)

Table 3: Features of the Beetle ESP32 Wi-Fi

Heart-rate Sensor | 3.3 | 10 | 33
ECG Sensor | 3.3 | 10 | 33
Wi-Fi Module | 3.7 | 120 | 444
Total | | 140 | 510
Estimated Efficiency | | | 50%
Input Power Needed (mW) | | | 1020

The medical bracelet requires a power source which also complies to certain features:

- Rechargeability
- Small size
- Low mass

Therefore, it was decided that the medical bracelet would be powered by a Lithium Polymer

Rechargeable Battery with nominal voltage of 3.7 V and rated capacity of 190 mAh. This power

source agrees with the above requirements, as its size is 24 mm x 22 mm and it has low mass of

4.5 g [58]. Furthermore, according to the power budget calculated above the lifetime of the

battery will be:

t =

Input Energy
Input Power Needed =

3.7 × 190 × 10⁻³ Wℎ
1020 × 10⁻³ W

= 0.69 ℎ = 41.4 min

Additionally, the charging time is approximately 1 hour [58].

Battery Charger Module

In order to allow rechargeability of the bracelet, the RobotDyn® TP4056 Battery Charger Module

was used. This module includes a microUSB port for charging from a separate power source and

offers the following features [59]:

- Constant current of 1 A / Constant voltage of 4.2 V
- Current monitor
- Under voltage Lockout
- Two status LEDs

### 2.4.2. Software Components

Two software components are necessary to be able to receive the information of heart rate and

ECG from the Wi-Fi module and display the results in a user-friendly environment. One of the aims

of the project is to provide flexibility in the way that users and doctors view the results, therefore

two means of displaying information were developed, an IoT Cloud Service (for computer users)

and a mobile application (for smartphone users). These were created by using the:

- Ubidots IoT Cloud Service and the
- Blynk App Development Platform

On one hand, Ubidots is an IoT platform in which developers can easily communicate data from

sensors and display them using different means of presentation, such as Line Charts, Graphs,

Histograms and more. It provides support with Arduino libraries for multiple Wi-Fi modules such

as the Beetle ESP32 used in this application.

On the other hand, the Blynk Development Platform aids in the development of mobile

applications compatible with Android OS version 4.2+ and iOS version 9+ [60]. Furthermore, Blynk

applications can receive data using Wi-Fi connection from a diverse set of Wi-Fi modules, including

the ESP32 module used here.

### 2.4.3. Mechanical Component

The electrical components on the PCB were assembled with the mechanical component of the

system to provide ease of use by the patients. This is a:

- 3D-printed bracelet case

The bracelet case has a compact design in order to fit all of the components in a small area.

### 2.4.4. Procedure

The code of the system was developed in an Integrated Development Environment compatible

with the Wi-Fi module, the IoT Cloud Service and the Mobile App Development Platform (Arduino

IDE, Ver. 1.8.11, Arduino, Italy).

In order to set up the Arduino IDE to be compatible with the Beetle ESP32 Wi-Fi module and

communicate the data to the Cloud, the following additional equipment/tools were needed:

- USB A to mini USB B cable

- Computer with installed Arduino IDE, Ver. 1.8.11.
- Ubidots IoT Cloud Service Account

The steps required to successfully implement the functionality of the system were the following:

- The Arduino IDE environment was initiated and the ESP32 support for the Arduino environment was installed so that the ESP32 Wi-Fi module could be accessed [61].
- The “FireBeetle-ESP32” from the “Board” options in the “Tools” drop-down menu was selected.
- The .zip file for the “PubSubClient.h” file was downloaded and included it as a library in the Arduino project along with the “WiFi” Arduino library [62].
- The strap was attached on the heart-rate sensor, so that it took the form of a bracelet.
- The heart-rate sensor was worn on the left wrist very tightly with the sensor touching the upper side of the wrist.
- The biomedical pads with the conductive gel were connected to the ECG electrode cables.
- The three ECG electrodes on the user’s body were attached according to the following figure:

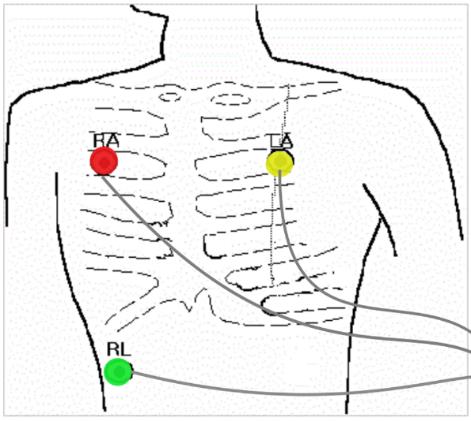
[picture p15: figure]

The connections made are summarized in the following table:

ECG Electrodes | Body parts
RA or R | Right part of the chest or Right arm
LA or L | Left part of the chest or Left arm
RL or F | Right part of the abdomen or Right leg
- The Wi-Fi module was connected to the Computer using the USB A to mini USB B cable.
- The main loop of the code used to implement the full functionality is shown in Appendix A.
- In the Arduino code the WIFISSID, PASSWORD variables were replaced according to the local network and a random MQTT_CLIENT_NAME was inserted for the device.
- The Arduino code was downloaded to the Wi-Fi module, which communicated the data to the Ubidots Cloud Service and the Blynk Mobile Application.

In order to set up the Ubidots IoT Cloud environment and display the results the following steps

were essential:

- A Ubidots Account was created at https://ubidots.com/.
- On the “Devices” screen, a new device was added named “esp32”.
- Inside the device options, two new variables were created called “Heart-rate” and “ECG”, which were assigned the instantaneous values of heart rate in BPM and the electric potential measured by the ECG device in order to produce the ECG graph respectively.
- On the “Dashboard” screen, two new widgets were created. One of them was a Metric and displayed the live measurement of the heart rate in BPM. The other one was a Double Axis graph, which demonstrated the live ECG graph of the user.
- The Heart-rate Metric widget was linked with the “Heart-rate” variable created before and the most recent value was displayed.
- The ECG Double Axis widget was linked with the “ECG” variable created before and it included “Time” as the x-axis and the “Amplitude” of the output voltage by the ECG sensor as the y-axis.

In order for the correct values to be displayed some changes were needed on the Arduino code:

- The Ubidots TOKEN was extracted from the website, by selecting “API Credentials” from the drop-down menu after clicking on the User image, and it was copied to the corresponding variable in the code.
- The variable labels were specified to be the same in the code as in the Ubidots cloud.
- The device label was specified to be the same as the one in the Ubidots cloud.

After the successful completion of this procedure, the system was ready to take measurements

from the user, communicate them to the IoT Cloud and the Mobile application, and display them

for analysis by a doctor.

An example of the dashboard displaying the Heart Rate measurement in BPM and the ECG graph is

shown:

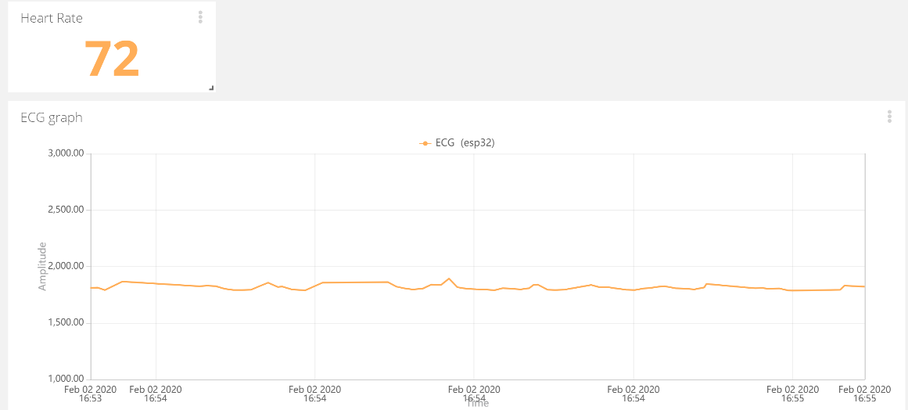
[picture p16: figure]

In order to set up the Blynk App Development Platform and create the Mobile App which will

display the results the following steps were essential:

ADD STEPS ON THE APP DEVELOPMENT

Testing

What components are used, how they are connected

### 2.5.1. Introduction

For each of the individual parts of the system, different off-the-shelf components were tested in

order to select the most suitable one for this application according to the design specifications and

priorities.

### 2.5.2. Testing of Sensors

Heart – rate sensor

In order to find the most suitable heart rate sensor for this application, two sensors are tested.

These are the following:

- DFRobot Gravity Heart Rate Monitor Sensor for Arduino
- Maxim Integrated MAXREFDES117#: Heart-rate and Pulse-oximetry monitor

As a benchmark of accuracy, the Heart Rate app on the Apple Watch Series 5 © [1] is used as well.

For the DFRobot Gravity Heart Rate Monitor Sensor:

In order to test the accuracy of this sensor, the following additional equipment is used:

- Microcontroller Board (Arduino UNO, Rev3, Arduino, Italy)
- Jumper Wires (Single-core)
- Computer with installed Integrated Development Environment compatible with the Microcontroller (Arduino IDE, Ver. 1.8.11, Arduino, Italy)

The steps followed for the set-up of the testing procedure are:

- Wear on the left wrist very tightly both DFRobot sensor and the Apple Watch Series 5 with the sensor touching the upper side of the wrist.
- Attach three stranded jumper wires in each of the pins of the female connector at the end of the DFRobot sensor.

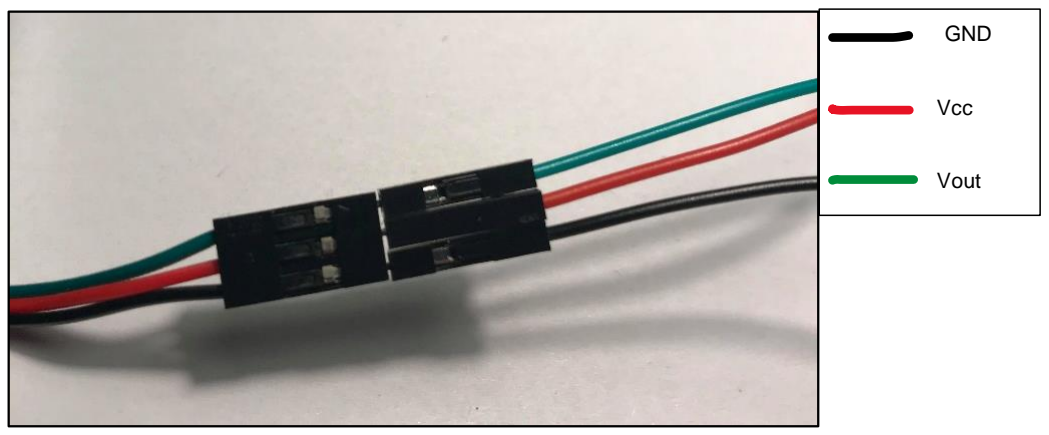
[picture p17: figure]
GND; Vcc; Vout

- Make the following connections of the DFRobot sensor to the Microcontroller board. For the Arduino UNO the connections are the following (mention connections – add diagram):
Arduino UNO | DFRobot Heart Rate Sensor
5V | Vcc
Analogue Pin A1 | Vout
GND | GND

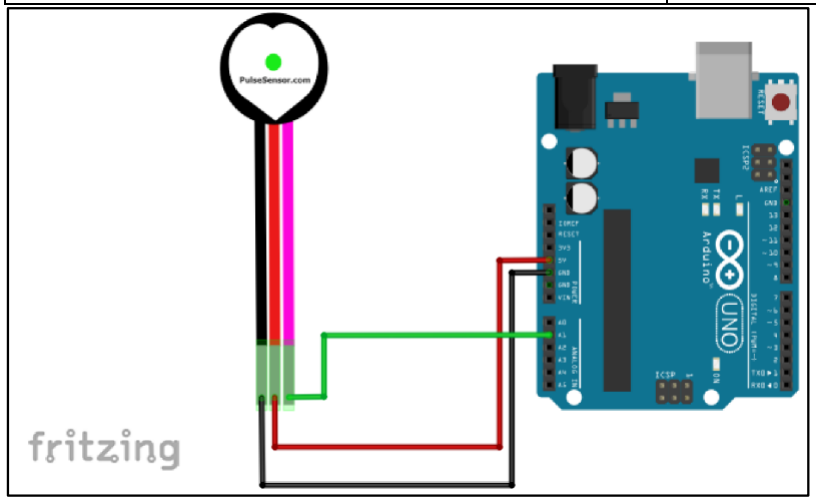
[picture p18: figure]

- Turn the switch on the sensor to the “Analogue” mode.
- Connect the Arduino UNO to the computer.
- Navigate to the GitHub page of the DFRobot sensor and download the libraries and the example code needed [63].
- Open the “DFRobot_Heartrate_Analog_Mode” file on the IDE and download the code shown in Appendix B to the Microcontroller board.
- Turn off any light sources which might cause interference to the sensor.
- Open the Serial Monitor.
- Open the Heart Rate app on the Apple Watch.
- Record a video showing both live measurements from the Apple Watch and the Serial Monitor for the DFRobot Gravity Heart Rate Sensor.
- Take 1 sample per second for 80 seconds.
- Input the recorded data to a spreadsheet (Microsoft Excel, Ver. 2010, Microsoft, Redmond, WA, USA).

- Plot a graph to show the accuracy of the sensor related to the measurements of the Apple Watch.
- Repeat process 3 times for validity of measurements.

Then the sensor’s accuracy is tested in many different conditions, such as analogue and digital

operation modes, above and below the wrist, with the arm moving during the measurement, with

wet arm and with ambient light sources turned on. The graphs demonstrating the outcomes are

presented in the Results section.

For the MAXREFDES#117 Sensor:

In order to test the accuracy of this sensor, the same additional equipment as above is used.

The steps required for the set-up of the testing procedure are the following:

- Wear tightly on the left wrist the Apple Watch with the sensor touching the upper side of the wrist.
- Solder five stranded jumper wires in each of the pins of the sensor PCB.

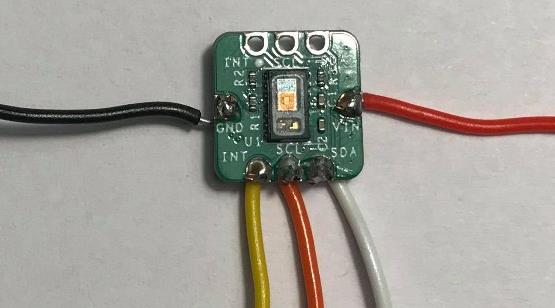
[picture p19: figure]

- Connect the MAXREFDES#117 sensor to the Microcontroller board. The connections to the Arduino UNO in this case are:
Arduino UNO | MAXREFDES#117
3.3V | Vin
GND | GND
SDA | SDA
SCL | SCL
Digital Pin 10 | INT

GND

Vin

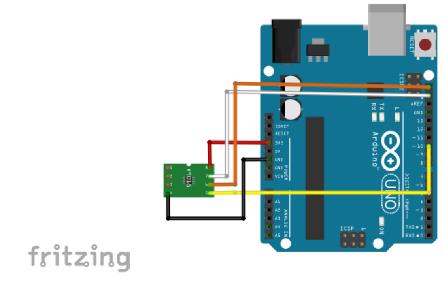
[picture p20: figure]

- Connect the Arduino UNO to the Computer.
- Navigate to the Maxim Integrated manufacturer website and download the design files which include an example code [64].
- Open the “RD117_ARDUINO” file on the IDE and download the code shown in Appendix C to the Microcontroller board.
- Turn off any light sources which might cause interference to the sensor.
- Open the Serial Monitor.
- Open the Heart Rate app on the Apple Watch.
- Record a video showing both live measurements from the Apple Watch and the Serial Monitor for the MAXREFDES#117 Sensor.
- Take 1 sample per second for 80 seconds.
- Input the recorded data to a spreadsheet (Microsoft Excel, Ver. 2010, Microsoft, Redmond, WA, USA).
- Plot a graph to show the accuracy of the sensor related to the measurements of the Apple Watch.
- Repeat process 3 times for validity of measurements.

The sensor is then tested under the same conditions as the DFRobot Sensor in order to compare

performance and decide on the most suitable sensor for the device.

ECG Sensor

As far as the Electrocardiograph (ECG) sensor is concerned, there is a limited number of off-the-

shelf components. For that case, one sensor is tested, the Gravity Analog ECG sensor for Arduino.

As a benchmark of accuracy, the Heart Rate app on the Apple Watch Series 5 [1] is used here too.

In order to test the accuracy of this sensor, the following additional equipment is used:

- Microcontroller Board (Arduino UNO, Rev3, Arduino, Italy)
- Jumper Wires (Single-core)
- Computer with installed Integrated Development Environment compatible with the Microcontroller (Arduino IDE, Ver. 1.8.11, Arduino, Italy)
- 3 x Biomedical Sensor Pads

The testing procedure includes:

- Connect the biomedical pads to the three electrodes and remove the plastic protection.

- Attach the three electrodes on the body of the user according to the configuration explained in the “Implementation” section (Figure k – mention the one for the placement of the electrodes in that section).
- Wear on the left wrist very tightly the Apple Watch Series 5 with the sensor touching the upper side of the wrist.
- Attach three stranded jumper wires in each of the pins of the female connector at the end of the Gravity Analog ECG sensor.

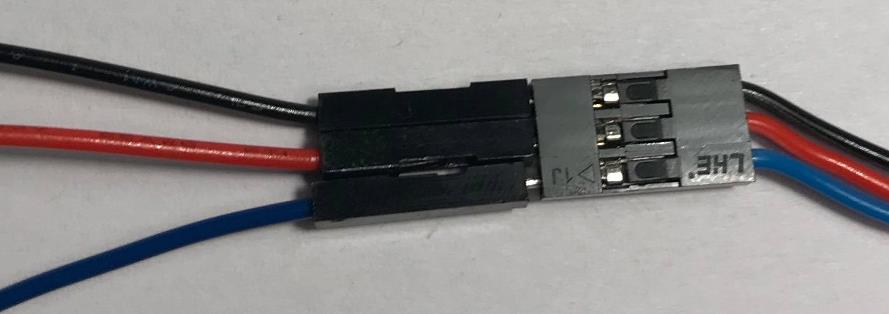
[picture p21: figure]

- Make the following connections of the ECG sensor to the Microcontroller board. For the Arduino UNO the connections are the following:
Arduino UNO | Gravity Analog ECG Sensor
5V | Vcc
GND | GND
Analogue Pin A1 | Vout

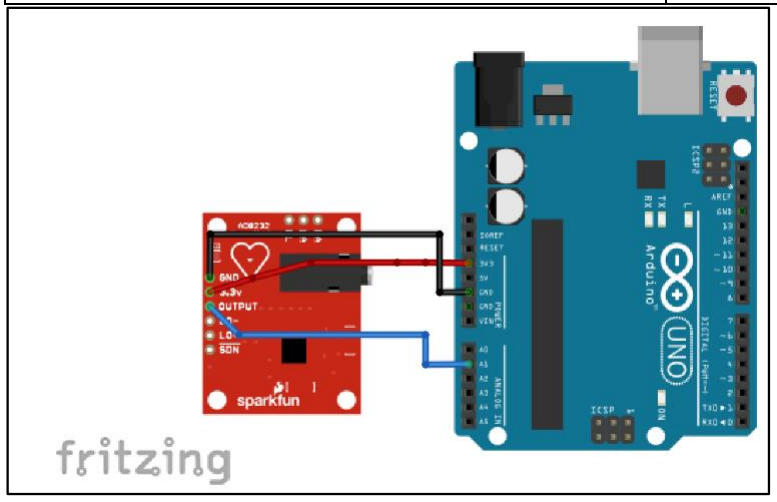
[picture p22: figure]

- Connect the Arduino UNO to the computer.
- Navigate to the GitHub page of the DFRobot sensor and use the sample code given [65].
- Open the sample code, shown in Appendix D, on the IDE and download it to the Microcontroller board.
- Open the Serial Plotter.
- Open the Heart Rate app on the Apple Watch.
- Save a snapshot of the recorded ECG graph recorded from the Gravity Analog Sensor.
- Save the ECG graph recorded from the Apple Watch into a PDF and compare the results, which are demonstrated in the “Results” section.

GND

Vcc

Wi-Fi Modules

The data acquired by the sensors will be transmitted to the network by using a Wi-Fi module. Two

off-the-shelf components are tested to compare performance and by considering further

parameters such as size and cost to decide on the most suitable one for the medical bracelet. The

functionality of the Wi-Fi modules is tested by transferring data from the heart-rate sensor to the

Ubidots IoT cloud, in order to display them in a user-friendly environment.

For the ESP32-DevKitC V4 Wi-Fi module:

The following additional equipment is needed:

- Prototyping board
- Heart – rate sensor with three attached jumper wires (the same wires as before)
- USB A to mini USB B cable
- Computer with installed Arduino IDE, Ver. 1.8.11.
- Ubidots IoT Cloud Service Account

The steps followed to successfully test the functionality of the ESP32-DevKitC Wi-Fi module

include:

- Open the Arduino IDE environment.
- Install the ESP32 support for the Arduino environment so that the ESP32 Wi-Fi module can be accessed.
- Select the “ESP32 Dev Module” from the “Board” options in the “Tools” drop-down menu.
- Download the .zip file for the “PubSubClient.h” file and include it as a library in the Arduino project along with the “WiFi” Arduino library.
- Place the Wi-Fi module on the prototype board.
- Make the following connections from the Heart-rate Sensor to the Wi-Fi module on the prototype board:
ESP32 Wi-Fi module | Heart-rate Sensor
5V | Vcc
GND | GND
VP | Vout
- Wear on the left wrist very tightly the heart-rate sensor with the sensor touching the upper side of the wrist.
- Connect the Wi-Fi module to the Computer using the USB A to mini USB B cable.

- In the Arduino code replace the WIFISSID, PASSWORD according to the local network as well as the TOKEN from the Ubidots account and a random MQTT_CLIENT_NAME.
- Download the Arduino code, shown in Appendix E, to the Wi-Fi module, which will communicate the data to the Ubidots Cloud Service.
- Live update of the heart rate in Beats per Minute (BPM) appears in the Dashboard of the device.

For the Beetle ESP32 Wi-Fi module:

The same steps and code were used to test the Beetle ESP32 Wi-Fi module. The data was sent

with the same efficiency as the two modules contain the same microcontroller and have similar

Wi-Fi capabilities. However, because the Beetle ESP32 module offers benefits in size (35 mm x 34

mm instead of 54 mm x 28 mm for the ESP32-DevKitC V4 Wi-Fi module), it is selected for the

medical bracelet presented here.

Results
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

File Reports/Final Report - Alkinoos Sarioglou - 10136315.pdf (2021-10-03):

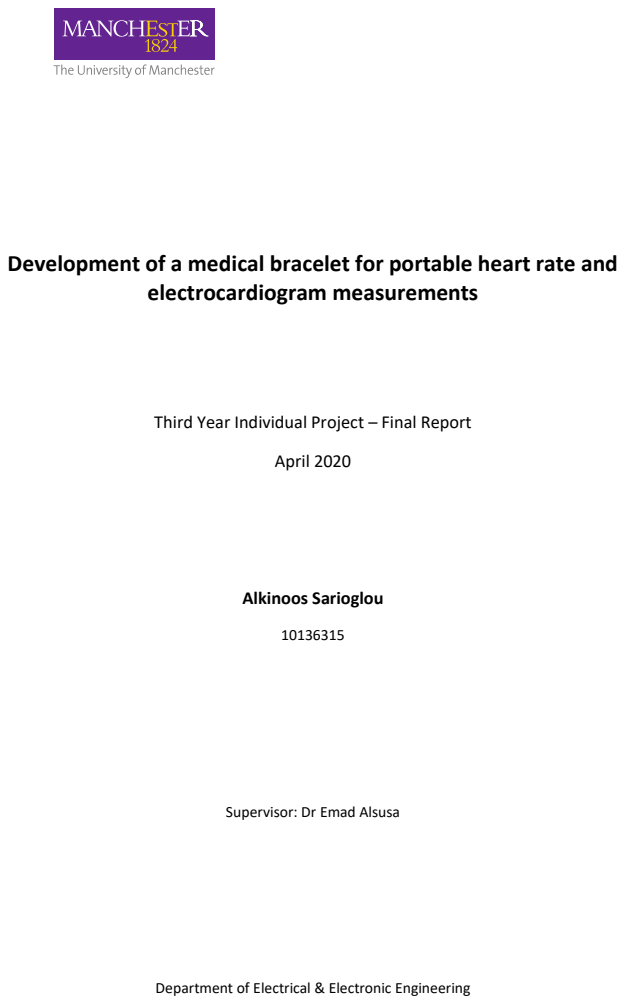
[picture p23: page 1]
electrocardiogram measurements; April 2020; Alkinoos Sarioglou

Development of a medical bracelet for portable heart rate and

Third Year Individual Project – Final Report

Supervisor: Dr Emad Alsusa

Department of Electrical & Electronic Engineering

Department of Electrical & Electronic Engineering

Abstract

It is a fact that heart attacks have always been one of the biggest causes of death worldwide. The

most effective way of predicting their occurrence nowadays is heart monitoring, which refers to

tracking the electrical activity of the heart in order to detect abnormalities of its operation and

enable immediate action. There are two important medical tools enabling heart monitoring, the

heart rate monitor and the electrocardiograph (ECG). This project is related to the development of

a portable medical bracelet which combines both instruments, in order to make early detection of

heart irregularities easily accessible to more people. In contrast with the available state-of-the-art,

this device focused on providing benefits such as low cost, less complexity of use and more

effective communication of the results to the user’s doctor, while also incorporating the features

of sensor accuracy and neat presentation of the results on an Internet of Things (IoT) Cloud

Webpage and a Mobile Application (App). The device produced heart rate measurements with

error of 0.46% when compared to the benchmark device which suggests that it could be used in

real-life situations to provide doctors with useful monitoring data on their patients’ health

condition and potentially save lives.

Department of Electrical & Electronic Engineering | Page i

Contents

Abstract

Department of Electrical & Electronic Engineering | Page ii

Department of Electrical & Electronic Engineering | Page iii
Appendix 6 | 52
Appendix 7 | 56
Appendix 8 | 57
Appendix 9 | 61

Figures

Figure 1: Historical Timeline of Electrocardiography and Photoplethysmography | 5
Figure 2: Operation of a PPG Sensor | 12
Figure 3: Deflections of an ECG Graph | 12
Figure 4: Einthoven’s Triangle | 13
Figure 5: Methodology Flowchart | 14
Figure 6: PCB Layout Diagram | 15
Figure 7: Configuration of Levels | 16
Figure 8: Bracelet Case 3D CAD Design, Figure 9: Final Physical Product | 17
Figure 10: Attachment of ECG Electrodes | 21
Figure 11: Example Ubidots Dashboard | 21
Figure 12: Example Mobile App Pages | 22

Figure 13: Attached Wires in Connector of the DFRobot Gravity Heart Rate Monitor Sensor.........23

Figure 14: Soldered Wires on the MAXREFDES#117 Sensor | 23
Figure 15: Attached Wires in Connector of the Gravity Analog ECG Sensor for Arduino | 24
Figure 16: DFRobot – Test 1, Figure 17: DFRobot – Test 2 | 26
Figure 18: MAXREFDES#117 – Test 1, Figure 19: MAXREFDES#117 – Test 2 | 26
Figure 20: DFRobot – Above Wrist, Figure 21: DFRobot – Below Wrist | 27
Figure 22: DFRobot – Analogue, Figure 23: DFRobot – Digital | 28
Figure 24: DFRobot – Arm Moving | 29
Figure 25: DFRobot – Humid Skin | 29
Figure 26: DFRobot – Ambient Light | 29
Figure 27: Dynamic Signal Analyzer Output of the ECG Signal | 30
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

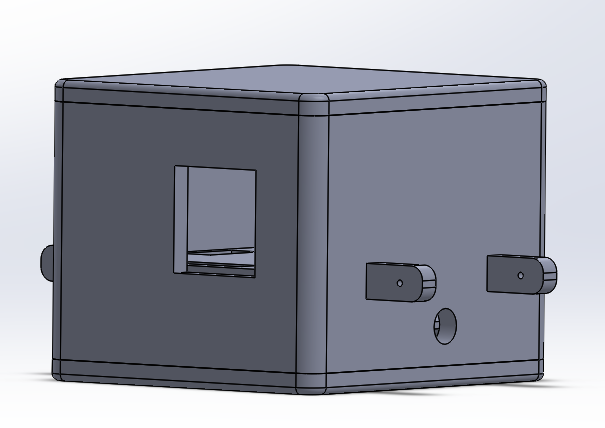
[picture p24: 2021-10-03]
CAD_Models/Overview.png

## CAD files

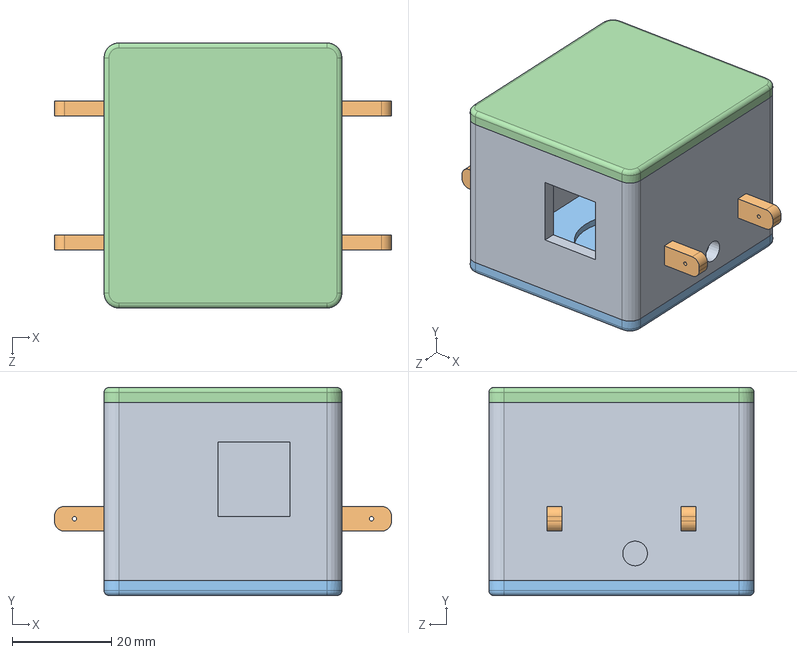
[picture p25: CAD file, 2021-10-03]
CAD_Models/System Assembly.SLDASM
68.0 x 42.0 x 53.5 mm
Side_Walls
Watch_Lug x 4
Bottom_Layer
Part_2_3D_Print_Top_Cover

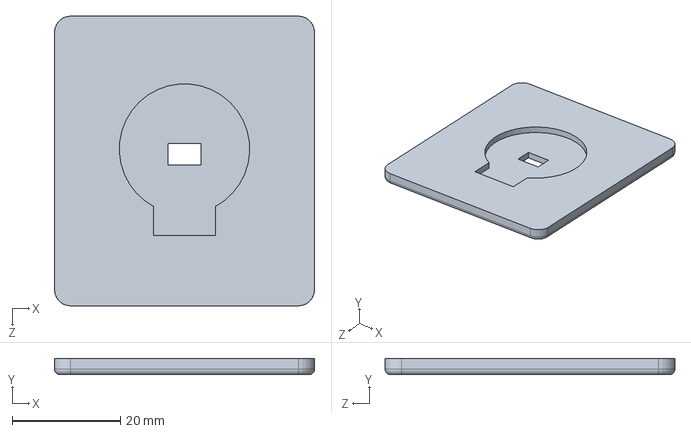
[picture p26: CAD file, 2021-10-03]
CAD_Models/Bottom_Layer.SLDPRT
48.0 x 3.00 x 53.5 mm

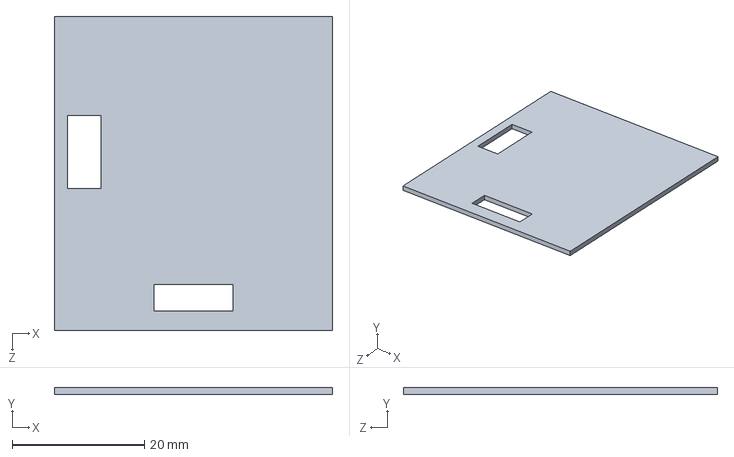
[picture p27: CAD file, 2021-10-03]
CAD_Models/Second_Intermediate_1_mm.SLDPRT
42.0 x 1.00 x 47.5 mm

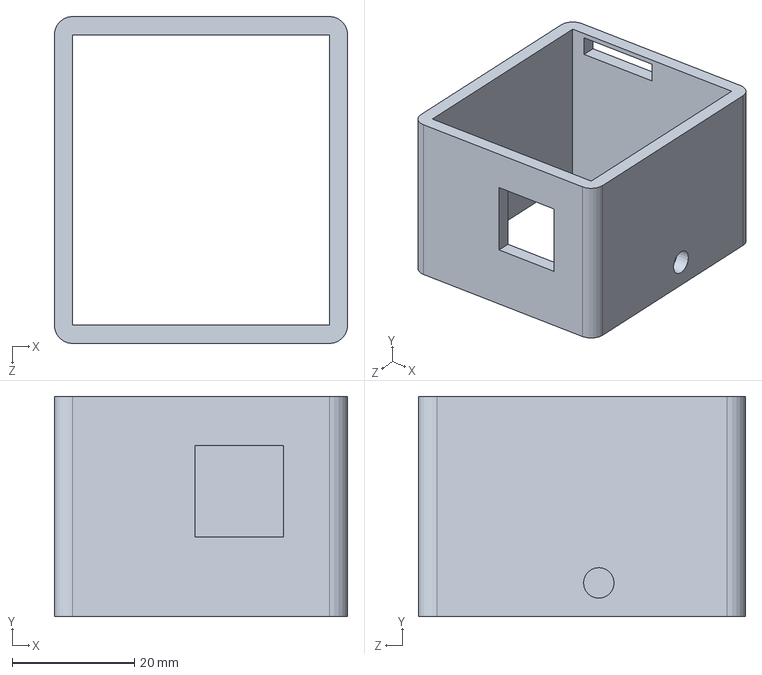
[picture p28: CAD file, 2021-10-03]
CAD_Models/Side_Walls.SLDPRT
48.0 x 36.0 x 53.5 mm

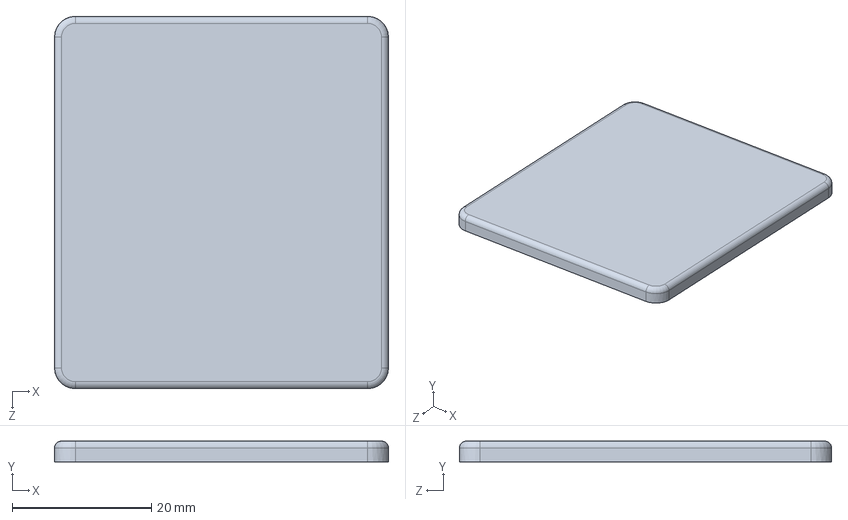
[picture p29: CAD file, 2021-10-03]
CAD_Models/Part_2_3D_Print_Top_Cover.SLDPRT
48.0 x 3.00 x 53.5 mm

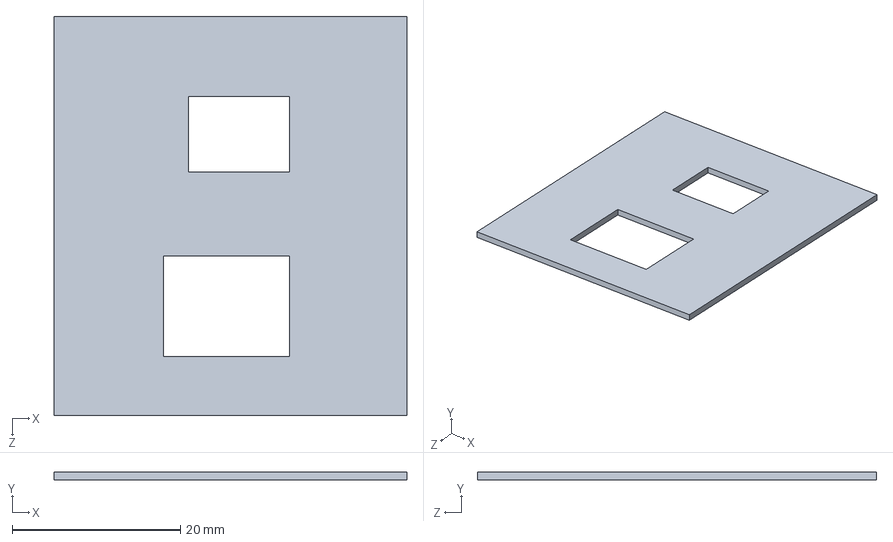
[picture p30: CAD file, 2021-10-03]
CAD_Models/First_Intermediate_1_mm.SLDPRT
42.0 x 1.00 x 47.5 mm

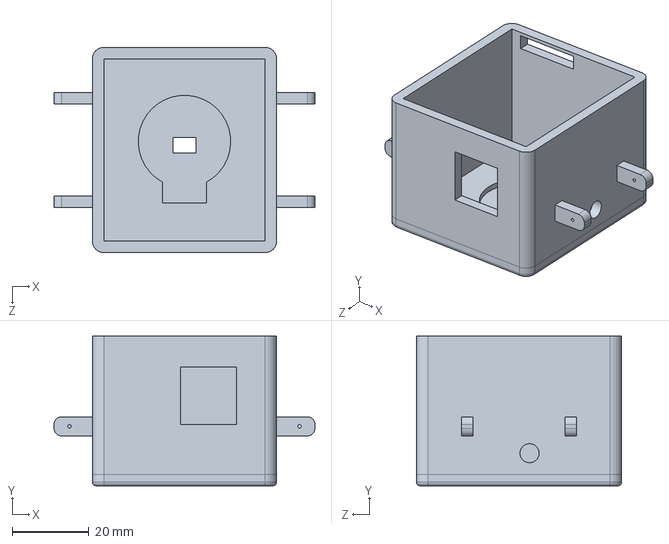
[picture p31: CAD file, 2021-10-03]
CAD_Models/Part_1_3D_Print_Bottom_Cover_and_Side_Walls.SLDPRT
68.0 x 39.0 x 53.5 mm

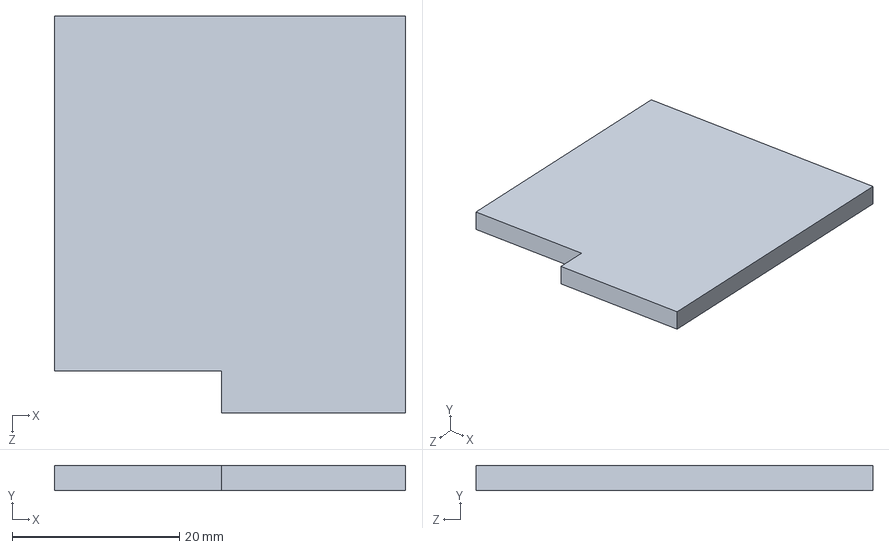
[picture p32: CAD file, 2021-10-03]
CAD_Models/Third_Intermediate_3_mm.SLDPRT
42.0 x 3.00 x 47.5 mm

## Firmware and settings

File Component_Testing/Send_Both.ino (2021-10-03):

/*!

  This program collects the Heart-rate and ECG data and communicates them to the Ubidots IoT Cloud Service

  CREDITS TO:
  @author linfeng(Musk.lin@dfrobot.com)
  Copyright (C) <2015>  <linfeng>
  The code of the above person was taken and modified to fit the needs of the Final-Year project of Alkinoos Sarioglou

  CREDITS TO:
  Blynk is a platform with iOS and Android apps to control
  Arduino, Raspberry Pi and the likes over the Internet.
  You can easily build graphic interfaces for all your
  projects by simply dragging and dropping widgets.

  Blynk library is licensed under MIT license
  This example code is in public domain.

  /*************************************************************
  Download latest Blynk library here:
  https://github.com/blynkkk/blynk-library/releases/latest

 *************************************************************
  
*/

/******************************
   Wi-Fi ESP32
 ******************************/
#include <WiFi.h>
#include <PubSubClient.h>
/* Comment this out to disable prints and save space */
#define BLYNK_PRINT Serial


#include <WiFi.h>
#include <WiFiClient.h>
#include <BlynkSimpleEsp32.h>

#define WIFISSID "Vodafone" // Put your WifiSSID here
#define PASSWORD "1894cTiD9320" // Put your wifi password here
#define TOKEN "BBFF-Mw49RtL5lzGGpMTZsBkmacAUldbTnS" // Put your Ubidots' TOKEN
#define MQTT_CLIENT_NAME "bracelet" // MQTT client Name, please enter your own 8-12 alphanumeric character ASCII string; 
//it should be a random and unique ascii string and different from all other devices


// You should get Auth Token in the Blynk App.
// Go to the Project Settings (nut icon).
char auth[] = "05yGAThpz710HDISJQjMB049iTpB16kb";
float ecg_data;
int heart_rate_data;

/****************************************
   Define Constants
 ****************************************/
#define VARIABLE_LABEL "sensor" // Assing the variable label
#define DEVICE_LABEL "esp32" // Assig the device label

// https://industrial.api.ubidots.com/api/v1.6/devices/{your-device-label}/?type=heartly
char mqttBroker[]  = "industrial.api.ubidots.com";
char payload[100];
char topic[150];
// Space to store values to send
char str_sensor[10];

#define VARIABLE_LABEL_ECG "ecg-sensor" // Assing the variable label

#define SENSOR 35 // Set the A3/IO35 as SENSOR

BlynkTimer timer;

bool turn = true;
uint8_t rateValue;

/****************************************
   Auxiliar Functions
 ****************************************/
WiFiClient ubidots;
PubSubClient client(ubidots);

/***************************************
   Heart - Rate sensor
 ***************************************/
#define heartratePin 36
#include "DFRobot_Heartrate.h"

DFRobot_Heartrate heartrate(ANALOG_MODE); ///< ANALOG_MODE or DIGITAL_MODE

/***************************************
   Functions
 ***************************************/

void callback(char* topic, byte* payload, unsigned int length) {
  char p[length + 1];
  memcpy(p, payload, length);
  p[length] = NULL;
  Serial.write(payload, length);
  Serial.println(topic);
}

void reconnect() {
  // Loop until we're reconnected
  while (!client.connected()) {
    Serial.println("Attempting MQTT connection...");

    // Attemp to connect
    if (client.connect(MQTT_CLIENT_NAME, TOKEN, "")) {
      Serial.println("Connected");
    } else {
      Serial.print("Failed, rc=");
      Serial.print(client.state());
      Serial.println(" try again in 2 seconds");
      // Wait 2 seconds before retrying
      delay(2000);
    }
  }
}


/* ECG Data  */
// This function sends Arduino's up time every second to Virtual Pin (5).
// In the app, Widget's reading frequency should be set to PUSH. This means
// that you define how often to send data to Blynk App.
void myTimerEvent()
{
  // You can send any value at any time.
  // Please don't send more that 10 values per second.
  ecg_data =  analogRead(SENSOR); // Read ECG Data
  if (rateValue)  heart_rate_data = rateValue;    // Read Heart Rate Data
  Blynk.virtualWrite(V5, ecg_data); // Send ECG Data
  Blynk.virtualWrite(V3, heart_rate_data); // Send Heart Rate Data
}

/****************************************
   Main Functions
 ****************************************/
void setup() {
  Serial.begin(115200);
  WiFi.begin(WIFISSID, PASSWORD);
  Blynk.begin(auth, WIFISSID, PASSWORD);
  // Setup a function to be called every second for sending the values to the Mobile App
  timer.setInterval(300L, myTimerEvent);
  // Assign the pin as INPUT
  pinMode(heartratePin, INPUT);
  pinMode(SENSOR, INPUT);

  Serial.println();
  Serial.print("Waiting for WiFi...");

  while (WiFi.status() != WL_CONNECTED) {
    Serial.print(".");
    delay(500);
  }

  Serial.println("");
  Serial.println("WiFi Connected");
  Serial.println("IP address: ");
  Serial.println(WiFi.localIP());
  client.setServer(mqttBroker, 1883);
  client.setCallback(callback);
}
 


void loop() {
  if (!client.connected()) {
    reconnect();
  }

  Blynk.run();
  timer.run(); // Initiates BlynkTimer, running timer every second

  if (turn == true) {
    sprintf(topic, "%s%s", "/v1.6/devices/", DEVICE_LABEL);
    sprintf(payload, "%s", ""); // Cleans the payload
    sprintf(payload, "{\"%s\":", VARIABLE_LABEL); // Adds the variable label

    heartrate.getValue(heartratePin); ///< A1 foot sampled values
    rateValue = heartrate.getRate(heartratePin); ///< Get heart rate value
    if (rateValue)  {
      Serial.println(rateValue);
      dtostrf((float)rateValue, 4, 0, str_sensor);
      sprintf(payload, "%s {\"value\": %s}}", payload, str_sensor); // Adds the value
      Serial.println("Publishing BPM data to Ubidots Cloud");
      turn = false;
      client.publish(topic, payload);
      client.loop();
    }
    delay(20);
  }

  if (turn == false) {
    sprintf(topic, "%s%s", "/v1.6/devices/", DEVICE_LABEL);
    sprintf(payload, "%s", ""); // Cleans the payload
    sprintf(payload, "{\"%s\":", VARIABLE_LABEL_ECG); // Adds the variable label

    float sensor = analogRead(SENSOR);

    /* 4 is mininum width, 2 is precision; float value is copied onto str_sensor*/
    dtostrf(sensor, 4, 2, str_sensor);

    sprintf(payload, "%s {\"value\": %s}}", payload, str_sensor); // Adds the value
    Serial.println("Publishing ECG data to Ubidots Cloud");
    turn = true;
    client.publish(topic, payload);
    client.loop();
    delay(10);
  }

}

/******************************************************************************
  Copyright (C) <2015>  <linfeng>
  This program is free software: you can redistribute it and/or modify
  it under the terms of the GNU General Public License as published by
  the Free Software Foundation, either version 3 of the License, or
  (at your option) any later version.
  This program is distributed in the hope that it will be useful,
  but WITHOUT ANY WARRANTY; without even the implied warranty of
  MERCHANTABILITY or FITNESS FOR A PARTICULAR PURPOSE.  See the
  GNU General Public License for more details.
  You should have received a copy of the GNU General Public License
  along with this program.  If not, see <http://www.gnu.org/licenses/>.
  Contact: Musk.lin@dfrobot.com
 ******************************************************************************/

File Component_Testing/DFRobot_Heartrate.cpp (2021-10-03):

#include "DFRobot_Heartrate.h"

#define debug_ 1

uint16_t value[SAMPLE_NUMBER]={0}; ///< Initialize sampling point value

/*!
* @brief Get a Sample values
*
* @brief  Get a Sample values
*
* @return uint16_t
*/ 
uint16_t DFRobot_Heartrate::getValue(uint8_t pin) 
{
	valueCount_++;
    if(valueCount_ >= SAMPLE_NUMBER){
        valueCount_ = 0;
    }    
	value[valueCount_] = analogRead(pin);  
    return(value[valueCount_]);

}

/*!
* @brief Get a sample
*
* @brief  Get the current location
*
* @return uint8_t
*/ 
uint8_t DFRobot_Heartrate::getCnt(void) 
{
    return(valueCount_);
}

/*!
* @brief Points to a valid node of the wave rise
*
* @brief  When the sampling point value increased 4 times in a row, considered to be a heartbeat
*
* @return char
*/ 

char DFRobot_Heartrate::maxNumber(uint8_t count)
{
	uint16_t temp1,temp2;
	for(int i=0;i<4;i++){
		if(count<i){
			temp1 = SAMPLE_NUMBER+count-i;
		}else{
			temp1 = count-i;
		}
		if(count<i+1){
			temp2 = SAMPLE_NUMBER+(count-1)-i;
		}else{
			temp2 = (count-1)-i;
		}		
		if(value[temp1]<=value[temp2])return(0);
	}
	if(valueFlag){
		valueFlag=1;
		return(0);
	}else{
		valueFlag=1;
		return(1);
	}	
}

/*!
* @brief Waveform down processing
*
* @brief  When the sample values decreased four times in a row, clear the heartbeat
*
* @return void
*/ 

void DFRobot_Heartrate::minNumber(uint8_t count)
{
	uint16_t temp1,temp2;
	for(int i=0;i<4;i++){
		if(count<i){
			temp1 = SAMPLE_NUMBER+count-i;
		}else{
			temp1 = count-i;
		}
		if(count<i+1){
			temp2 = SAMPLE_NUMBER+(count-1)-i;
		}else{
			temp2 = (count-1)-i;
		}		
		if(value[temp1]>=value[temp2])return;
	}
	valueFlag = 0;
	
}


/*!
* @brief Get heart rate value
*
* @brief  Sample ten times in a row beating heart rate value is computed
*
* @return uint16_t
*/ 

uint16_t DFRobot_Heartrate::analogGetRate(void)
{

	static uint8_t timeFlag;
	static unsigned long sampleTime[10];
	unsigned long valueTime_;
	minNumber(valueCount_);
	if(maxNumber(valueCount_)){       
        nowTim = millis();
		uint32_t difTime =  nowTim - lastTim;
        lastTim = nowTim;
        
        if(difTime>300 || difTime<2000){
            sampleTime[timeFlag++] = difTime;
            if(timeFlag > 9)timeFlag=0;
        }       
        if(0 == sampleTime[9]){
            Serial.println("Wait for valid data !"); 
            return(0);
        }
        		
		uint32_t Arrange[10]={0};		
		for(int i=0;i<10;i++){
            Arrange[i] = sampleTime[i];
        }
        uint32_t Arrange_=0;
        for(int i=9;i>0;i--){
            for(int j=0;j<i;j++){
                if(Arrange[j] > Arrange[j+1]){
                Arrange_ = Arrange[j];
                Arrange[j] = Arrange[j+1];
                Arrange[j+1] = Arrange_;
                }
            }            
        }   
		if((Arrange[7]-Arrange[3])>150){
            Serial.println("Wait for valid data !");  
			return(0);
		}	
        
        Arrange_ = 0;
		for(int i=3;i<=7;i++){
			Arrange_ += Arrange[i];
		}
		
		valueTime_ = 300000/Arrange_;///<60*1000*(7-2)	
		return((uint16_t)valueTime_);
	}	
	return(0);
}

/*!
* @brief Get heart rate value
*
* @brief  Sample ten times in a row beating heart rate value is computed
*
* @return uint16_t
*/ 

uint16_t DFRobot_Heartrate::digitalGetRate(void)
{

	static uint8_t timeFlag;
	static unsigned long sampleTime[10];
	unsigned long valueTime_;
	uint8_t count_;
	
	if(valueCount_){
		count_ = valueCount_-1;
	}else{
		count_ = SAMPLE_NUMBER-1;
	}
	if((value[valueCount_]>1000)&&(value[count_]<20)){       
        nowTim = millis();
		uint32_t difTime =  nowTim - lastTim;
        lastTim = nowTim;
        
        if(difTime>300 || difTime<2000){
            sampleTime[timeFlag++] = difTime;
            if(timeFlag > 9)timeFlag=0;
        }       
        if(0 == sampleTime[9]){
            Serial.println("Wait for valid data !"); 
            return(0);
        }
        		
		uint32_t Arrange[10]={0};		
		for(int i=0;i<10;i++){
            Arrange[i] = sampleTime[i];
        }
        uint32_t Arrange_=0;
        for(int i=9;i>0;i--){
            for(int j=0;j<i;j++){
                if(Arrange[j] > Arrange[j+1]){
                Arrange_ = Arrange[j];
                Arrange[j] = Arrange[j+1];
                Arrange[j+1] = Arrange_;
                }
            }            
        }   
		if((Arrange[7]-Arrange[3])>120){
            Serial.println("Wait for valid data !");  
			return(0);
		}	
        
        Arrange_ = 0;
		for(int i=3;i<=7;i++){
			Arrange_ += Arrange[i];
		}
		
		valueTime_ = 300000/Arrange_;///<60*1000*(7-2)	
		return((uint16_t)valueTime_);
    }	
	return(0);

}

/*!
* @brief Get heart rate value
*
* @brief  Sample ten times in a row beating heart rate value is computed
*
* @return uint16_t
*/ 
uint16_t DFRobot_Heartrate::getRate(void)
{
	if(mode_ == DIGITAL_MODE){
		return(digitalGetRate());
	}else{
		return(analogGetRate());
	}
}



/******************************************************************************
  Copyright (C) <2015>  <linfeng>
  This program is free software: you can redistribute it and/or modify
  it under the terms of the GNU General Public License as published by
  the Free Software Foundation, either version 3 of the License, or
  (at your option) any later version.
  This program is distributed in the hope that it will be useful,
  but WITHOUT ANY WARRANTY; without even the implied warranty of
  MERCHANTABILITY or FITNESS FOR A PARTICULAR PURPOSE.  See the
  GNU General Public License for more details.
  You should have received a copy of the GNU General Public License
  along with this program.  If not, see <http://www.gnu.org/licenses/>.
  Contact: Musk.lin@dfrobot.com
 ******************************************************************************/
 

    
